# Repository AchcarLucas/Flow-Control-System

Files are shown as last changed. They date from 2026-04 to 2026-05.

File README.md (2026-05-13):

# 🚀 Monitor de Fluxo de Pessoas - Univesp - PI V




> [Sistema que verifica o fluxo de pessoas em um determinado local, registrando a entrada e a saída]

---

## 🔗 Integrantes do Grupo

| Nome Completo | NA |
| --- | --- |
| Livia Santos Paes | 2216192  |
| Lucas Campos Achcar | 23207401 |
| Luiz Fernando Sales Lemos | 2226810  |
| Maria Francisca Bezerra da Conceição | 2010316  |

---

## 📌 Sumário

* [Sobre o Projeto](#-sobre-o-projeto)
* [Tecnologias e Ferramentas](#-tecnologias-e-ferramentas)
* [Progresso do Desenvolvimento](#-progresso-do-desenvolvimento)
* [Estrutura do Projeto](#-estrutura-do-projeto)
* [Previa de Desenvolvimento](#-previa-de-desenvolvimento)

> 💡 **README Extra:**
> - [README Firmware](./Firmware/README.md)
> - [README Building Blocks](<./Building Blocks/README.md>)
> - [README Kicad Schematic](<./Kicad Schematic/README.md>)
> - [README Stripboard Schematic](<./Stripboard Schematic/README.md>)
---

## 🧩 Sobre o Projeto

O **Monitor de Fluxo de Pessoas** é uma solução de sistemas embarcados projetada para automatizar a contagem e o monitoramento de tráfego em ambientes fechados de forma autônoma e de baixo custo. O sistema utiliza um par de sensores ópticos infravermelhos para detectar não apenas a presença, mas a **direcionalidade do movimento**, permitindo distinguir com precisão entre entradas e saídas.

Diferente de soluções dependentes de nuvem, este projeto foca em **Edge Computing** (Processamento na Borda), onde a lógica de identificação de fluxo e o armazenamento dos registros ocorrem integralmente dentro do microcontrolador ESP32, garantindo privacidade e operabilidade mesmo sem conexão constante com a internet.

### 🧠 Diagrama de Blocos do Sistema

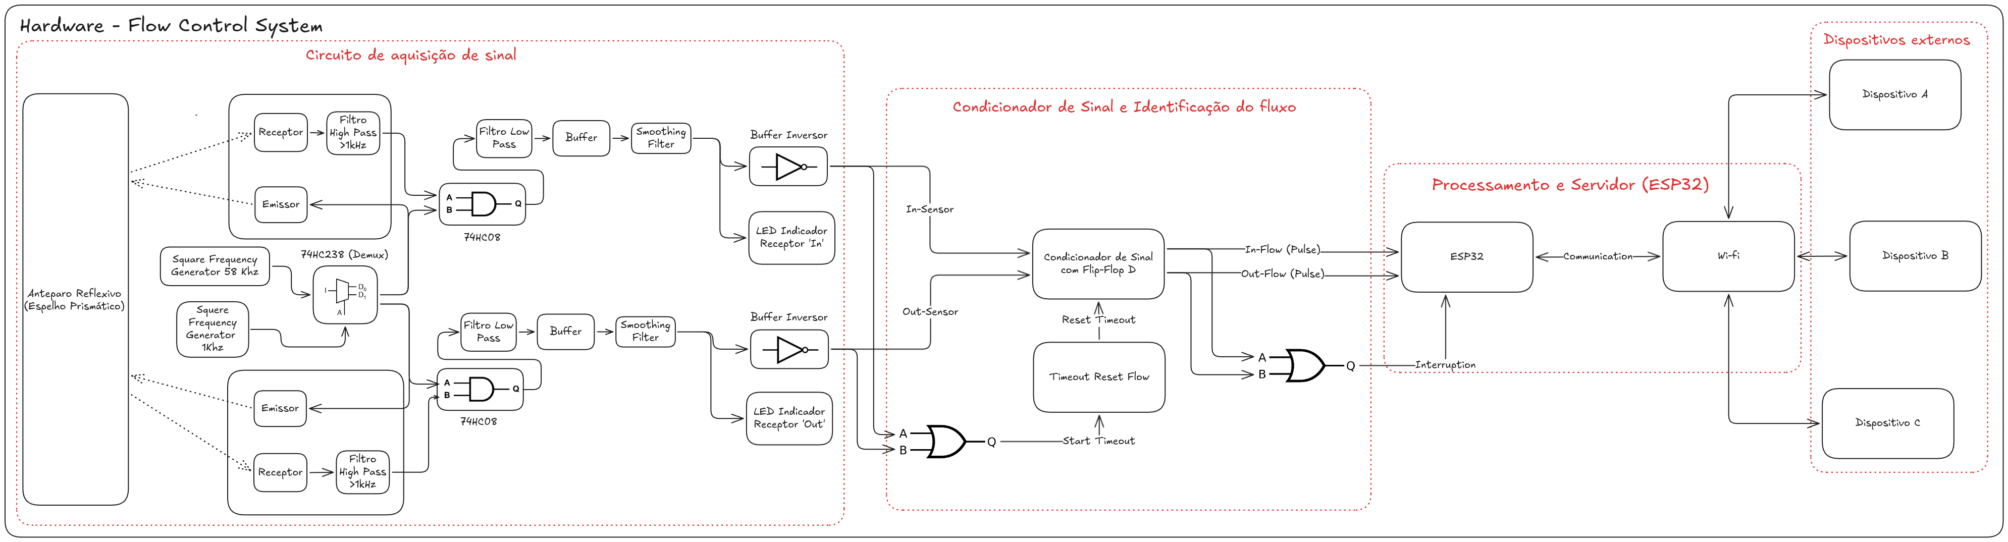
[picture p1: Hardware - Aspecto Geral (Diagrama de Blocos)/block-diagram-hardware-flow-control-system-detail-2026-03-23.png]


### ⚙️ Principais Funcionalidades

| Recurso | Descrição |
| :--- | :--- |
| **Detecção Direcional** | Circuito de tratamento de sinais que identifica o sentido do fluxo através do acionamento sequencial dos sensores. |
| **Condicionamento** | Circuito projetado para minimizar ruídos e falsos positivos, garantindo que a contagem reflita o fluxo real. |
| **Persistência Local** | Utilização da biblioteca **SQLite** para armazenamento robusto de logs no sistema de arquivos do ESP32, evitando perda de dados. |
| **Interface Web** | Servidor HTTP nativo que disponibiliza uma página para consulta em tempo real e visualização do histórico de acessos. |

---

## 🛠 Tecnologias e Ferramentas
* **Firmware:** [C++ | Arduino | PlatformIO]
* **Microcontrolador:** [ESP32 | ESP8266]
* **Linguagens:** [C++]
* **Banco de Dados:** [SQLite]
* **Simulações:** [SimulIDE]
* **CAD:** [Kicad e DIY Layout Creator]

## 🔧 Progresso do Desenvolvimento
|Status | Descrição |
| :--- | :--- |
| ✅ Concluído | Idealização do Projeto |
| ✅ Concluído | Prototipação do Enclosure do Fotosensor Utilizando CAD (Computer-Aided Design) |
| ✅ Concluído | Desenvolvimento do Firmware |
| ✅ Concluído | Alterações e Correções do Firmware |
| ✅ Concluído | Testes do Firmware para Identificação de Bugs e Leak de Memória |
| ✅ Concluído | Projeto e Prototipagem do Fotosensor |
| ✅ Concluído | Desenvolvimento da Enclusure para o Fotosensor |
| ✅ Concluído | Desenvolvimento do Schematic via Kicad |
| ✅ Concluído | Desenho dos Circuitos para Placa PadBoard usando a ferramenta DIY Layout Creator |
| ✅ Concluído | Teste do Circuito de Processamento na Protoboard|
| ✅ Concluído | Teste do Circuito de Aquisição de Sinal na Protoboard |
| ✅ Concluído | Teste do Circuito de Condicionamento, Identificação de Fluxo na Protoboard|
| ✅ Concluído | Desenvolvimento do Circuito de Fotosensor Placa PadBoard |
| ✅ Concluído | Desenvolvimento do Circuito de Aquisição de Sinal na Placa PadBoard |
| ✅ Concluído | Desenvolvimento do Circuito de Condicionamento, Identificação de Fluxo e Processamento na Placa PadBoard|
| ✅ Concluído | Prototipação do Enclosure da Mainboard Utilizando CAD |
| ✅ Concluído | Teste Final do Projeto na Todalidade |
| ✅ Concluído | Montagem Final do Projeto |

<!--
| ✅ Concluído | Text |
| 🟡 Desenvolvimento | Text |
| 🔴 Pendente | Text |
-->

## 📂 Estrutura do Projeto
Para facilitar a navegação, o projeto está dividido da seguinte forma:

```text
└── README.md                                           # [Detalhes do Projeto](./README.md)
├── Building Blocks/                                    # Prototipagem Geral do Sistema via CAD (SimulIDE)
    └── Processing e Server/                                    # Prototipação do ESP32 como WebServer e Processamento de Dados
    └── Emitter and Receiver                                    # Prototipação do Circuito do Fotosensor
    └── Signal Acquisition Circuit                              # Prototipação do Circuito de Aquisição de Sinais
    └── Signal Conditioning and Flow Identification Circuit     # Prototipação do Circuito de Condicionamento e Identificação de Fluxo
    └── README.md                                               # [Detalhes do Building Blocks](./Building Blocks/README.md)
├── Firmware/                                           # Código Fonte do Firmware do ESP32, Contém o WebServer e o Processamento de Sinais
    └── README.md                                               # [Detalhes do Firmware](./Firmware/README.md)
├── Hardware - Aspecto Geral (Diagrama de Blocos)/      # Idealização e Diagramação do Projeto Completo
├── Brainstorm/                                         # Brainstorm da Ideia Inicial
├── LTSpice/                                            # Simulações feitas via LTSpice para Auxilio do Desenvolvimento e Ajustes do Protótipo
├── Previa/                                             # Imagens e Animações de Previa do Projeto
├── Enclosure/                                          # Projeto das Cases Feito via FreeCAD
    └── FotosensorEnclosure                                     # Projeto da Case do Fotosensor feito em FreeCAD
    └── MainboardEnclosure                                      # Projeto da Case da Mainboard feito em FreeCAD
├── Kicad Schematic                                     # Schematic do Circuito Feito via Kicad
├── Stripboard Schematic/                               # Schematic do Circuito via DIY Layout Creator
```

## 🚀 Previa de Desenvolvimento

* ### Prototipo do Hardware para o Desenvolvimento do Firmware no ESP32

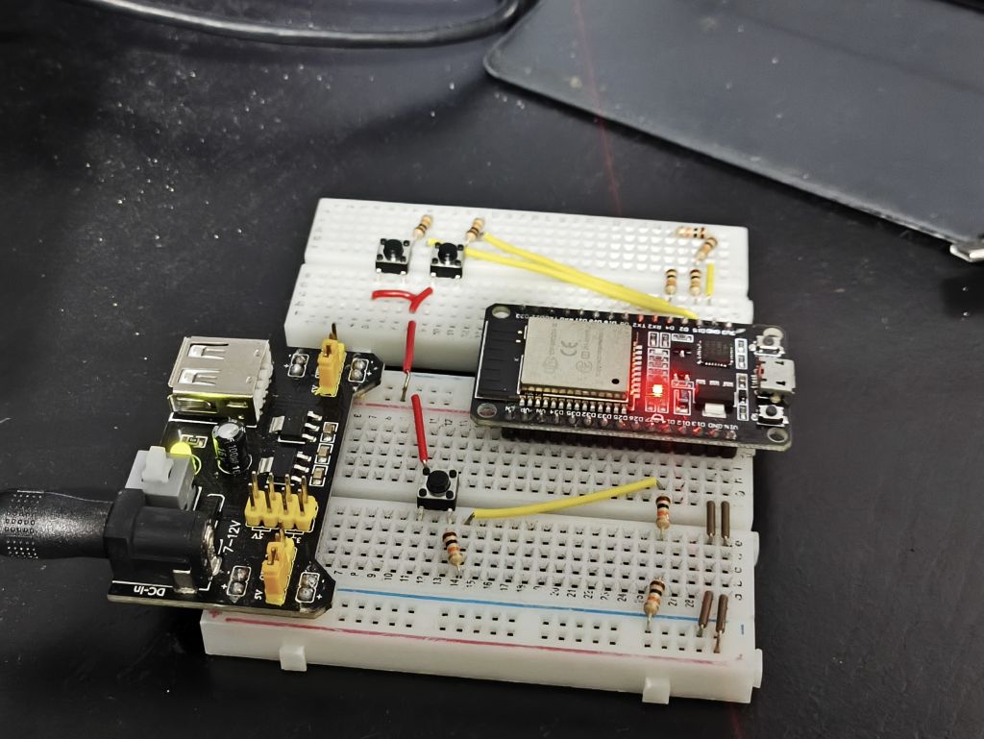
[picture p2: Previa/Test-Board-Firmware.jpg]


> 💡 **Detalhes da Placa de Teste:**
> - Os dois botões na parte de cima representam a entrada e a saída do fluxo.
> - O botão na parte de baixo representa a interrupção com detecção por borda de descida.

* ### Previa do 'Web Server' do Firmware

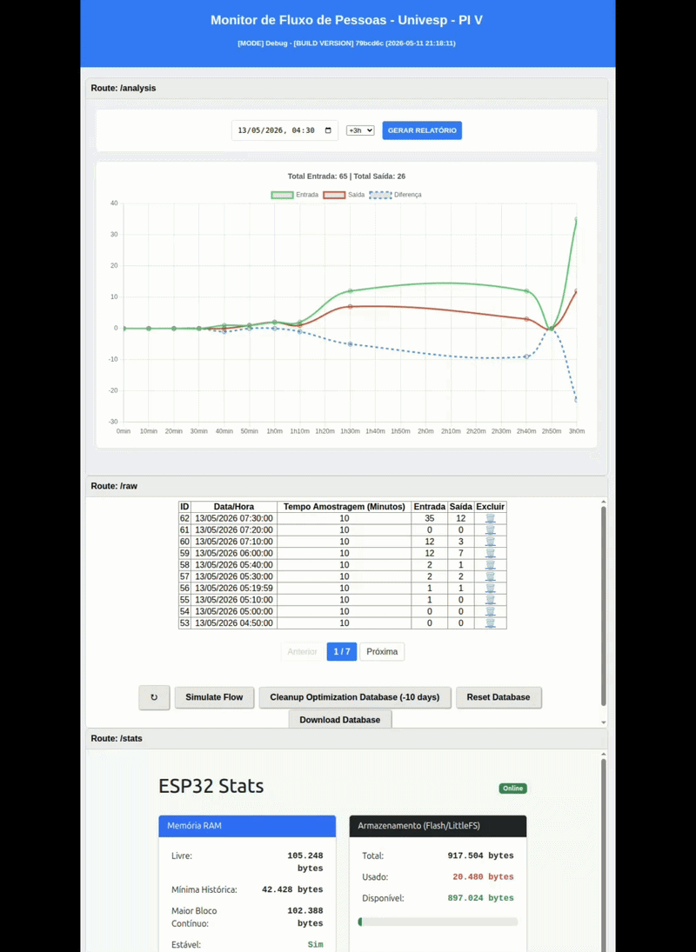
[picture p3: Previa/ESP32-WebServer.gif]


> 💡 **Detalhes do WebServer da Firmware:**
> - Servidor rodando diretamente no ESP32 - Edge Computing (Computador de Borda)
> - Gráfico para visualização dos dados em intervalos de horas
> - Planilha contendo os dados brutos (raw data)
> - Dashboard responsivo para celular e desktop.
> - Atualização em tempo real dos registros armazenados no SQLite.
> - Dashboard possui um sistema de stats para avaliação de desempenho do ESP32

* ### Protótipo do Circuito Completo em Protoboard

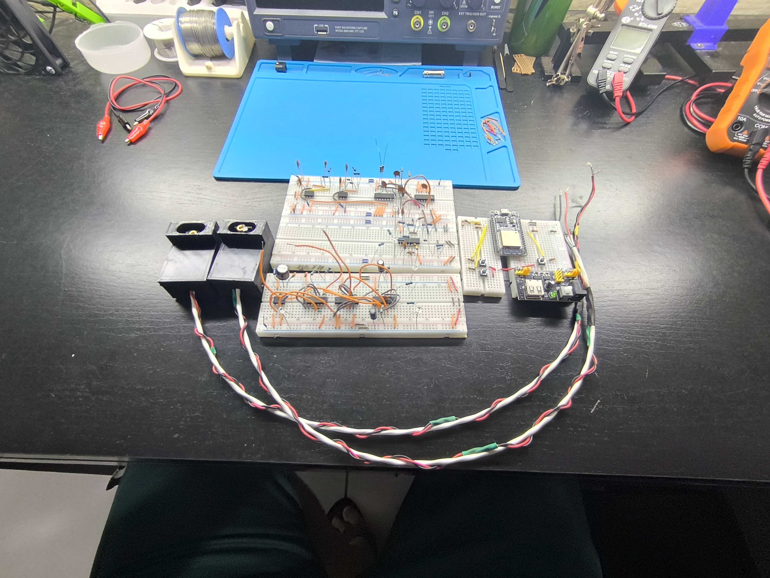
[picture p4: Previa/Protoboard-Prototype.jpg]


> 💡 **Detalhes do Protótipo:**
> - No canto esquerdo da imagem temos os dois fotosensores
> - No canto direito da imagem temos o prototipo do circuito de processamento
> - No centro superior da imagem temos o prototipo do circuito de condicionamento, identificação de fluxo 
> - No centro inferior da imagem temos o prototipo do circuito de aquisição de sinal

* ### Previa do Circuito Mainboard (Incompleto)

<div style="display: flex; gap: 10px;">
  
  
</div>

> 💡 **Detalhes do Circuito:**
> - Na esquerda, temos o circuito que faz a aquisição do sinal
> - Na direita, temos o circuito que faz o condicionamento e identificação do sentido além circuito de processamento (ESP32)
> - 📢 O circuito na direita ainda não esta completo

* ### Enclosure do Fotosensor

<div style="display: flex; gap: 10px;">
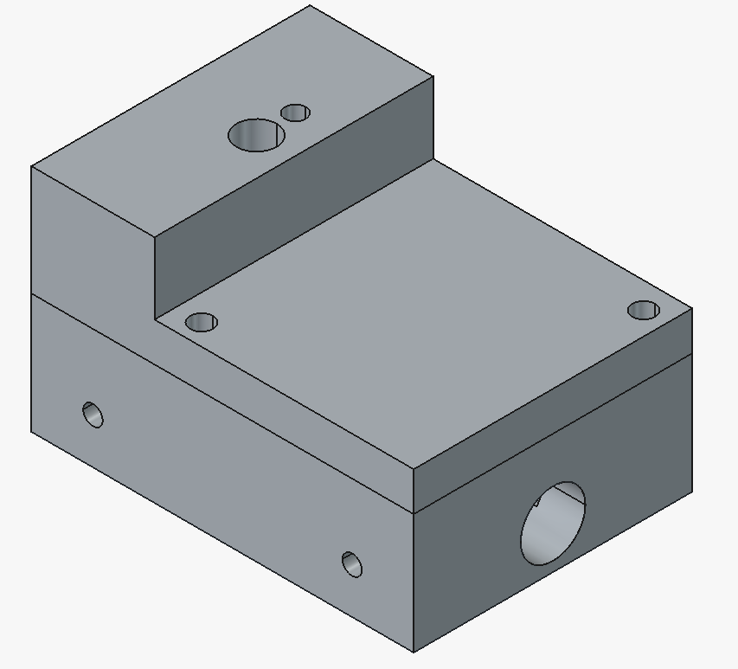
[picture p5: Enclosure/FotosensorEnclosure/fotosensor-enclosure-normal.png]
  
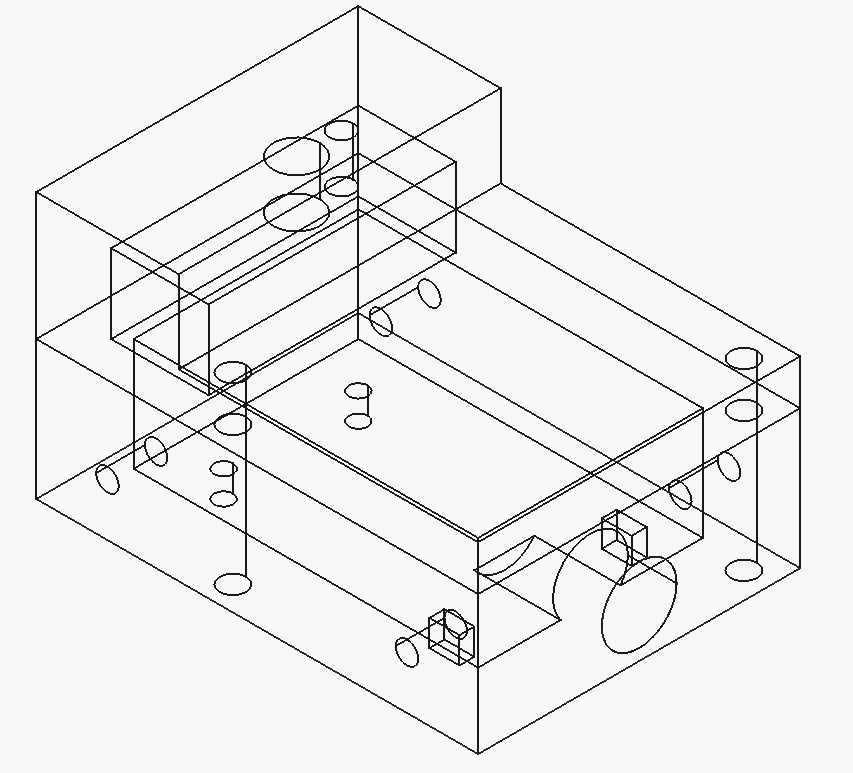
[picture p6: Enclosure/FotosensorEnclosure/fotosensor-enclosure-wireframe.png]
  
</div>

> 💡 **Detalhes do Enclosure do Fotosensor:**
> - [README FotosensorEnclosure](<./Enclosure/FotosensorEnclosure/README.md>)

* ### Enclosure da Mainboard

<div style="display: flex; gap: 10px;">
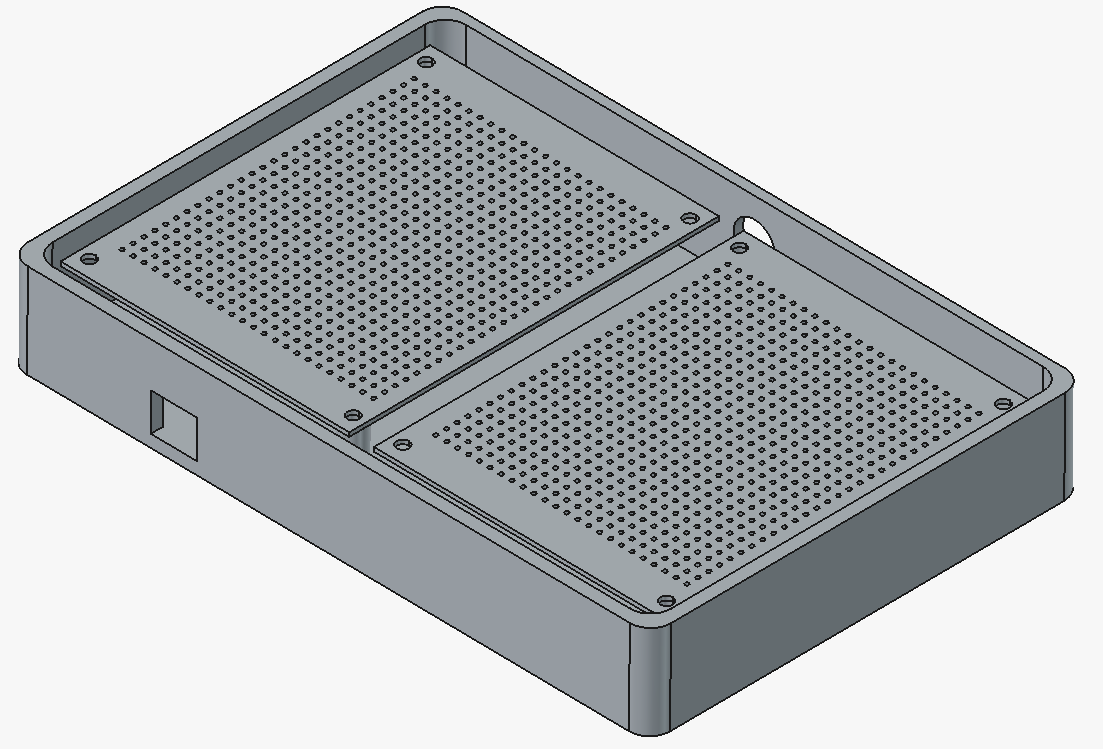
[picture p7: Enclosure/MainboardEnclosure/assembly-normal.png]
  
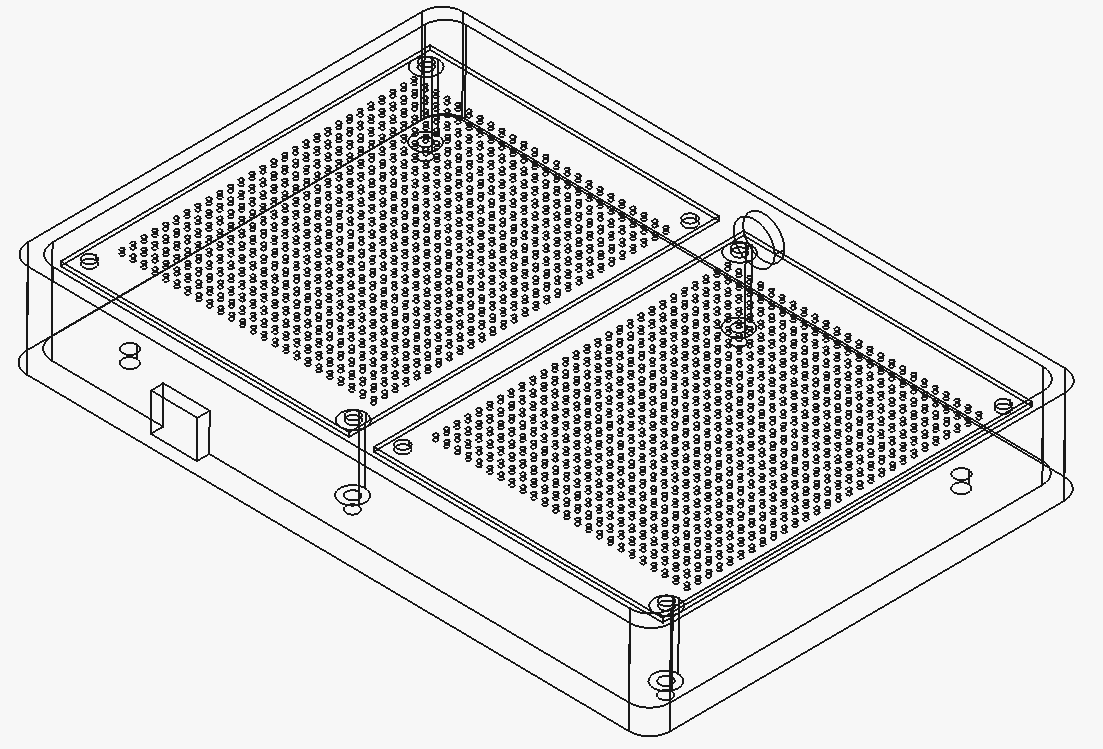
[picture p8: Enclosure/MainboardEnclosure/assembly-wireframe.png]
  
</div>

> 💡 **Detalhes do Enclosure da Mainboard:**
> - [README FotosensorEnclosure](<./Enclosure/MainboardEnclosure/README.md>)

## ✅ Projeto Concluído

<div style="display: flex; gap: 10px;">
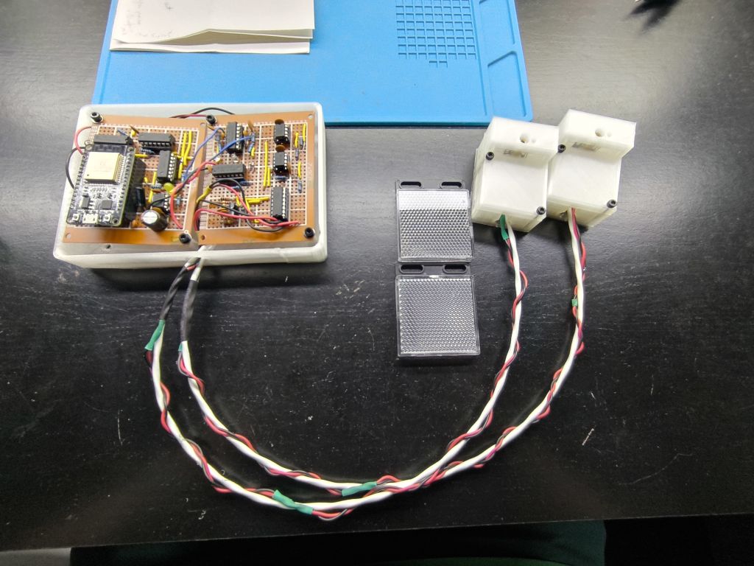
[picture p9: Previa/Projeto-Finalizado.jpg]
  
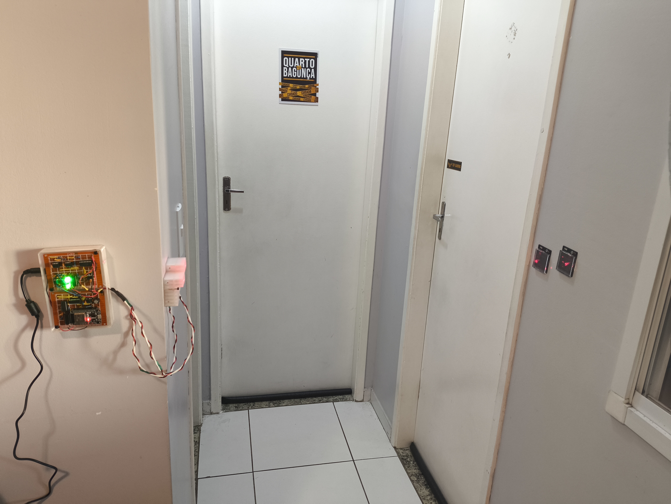
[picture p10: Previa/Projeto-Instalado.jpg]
  
</div>

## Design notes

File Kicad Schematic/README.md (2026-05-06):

# Projeto Integrador V - Monitor de Fluxo de Pessoas

Este diretório contém a documentação técnica, os esquemáticos eletrônicos e a lista de materiais (BOM) para o sistema de monitoramento de fluxo.

## 📂 Conteúdo do Diretório

O projeto é composto por três estágios principais, detalhados nos arquivos de imagem abaixo:

1.  **Emissor e Receptor (`emitter_and_receiver_schematic.png`)**:
    * Circuito de acionamento do diodo laser via transistor **BC547**.
    * Recepção de sinal via fototransistor **TIL78** com resistor de pull-up para gerar o sinal de saída.
2.  **Aquisição de Sinal (`signal_acquisition_schematic.png`)**:
    * Osciladores baseados no **NE555** para modulação em frequências distintas.
    * Filtragem ativa e demultiplexação utilizando portas **74LS08** e **74HC238** para garantir a imunidade a ruídos luminosos.
3.  **Condicionamento e Identificação de Fluxo (`signal_conditioning_and_flow_identification_schematic.png`)**:
    * Lógica de detecção de sentido (In/Out) utilizando Flip-Flops **74HC74**.
    * Tratamento de sinal com portas NAND Schmitt Trigger **4093** para debouncing e interface limpa com microcontroladores.
4.  **Processamento e Servidor (`processing-server-esp32-circuit.png`)**:
    * Receber o sinal de sentido (In-Flow/Out-Flow) nas portas do ESP32
    * Utilização de firmware para o sistema processamento e disponbilidade dos dados via web

<div style="display: flex; gap: 10px;">
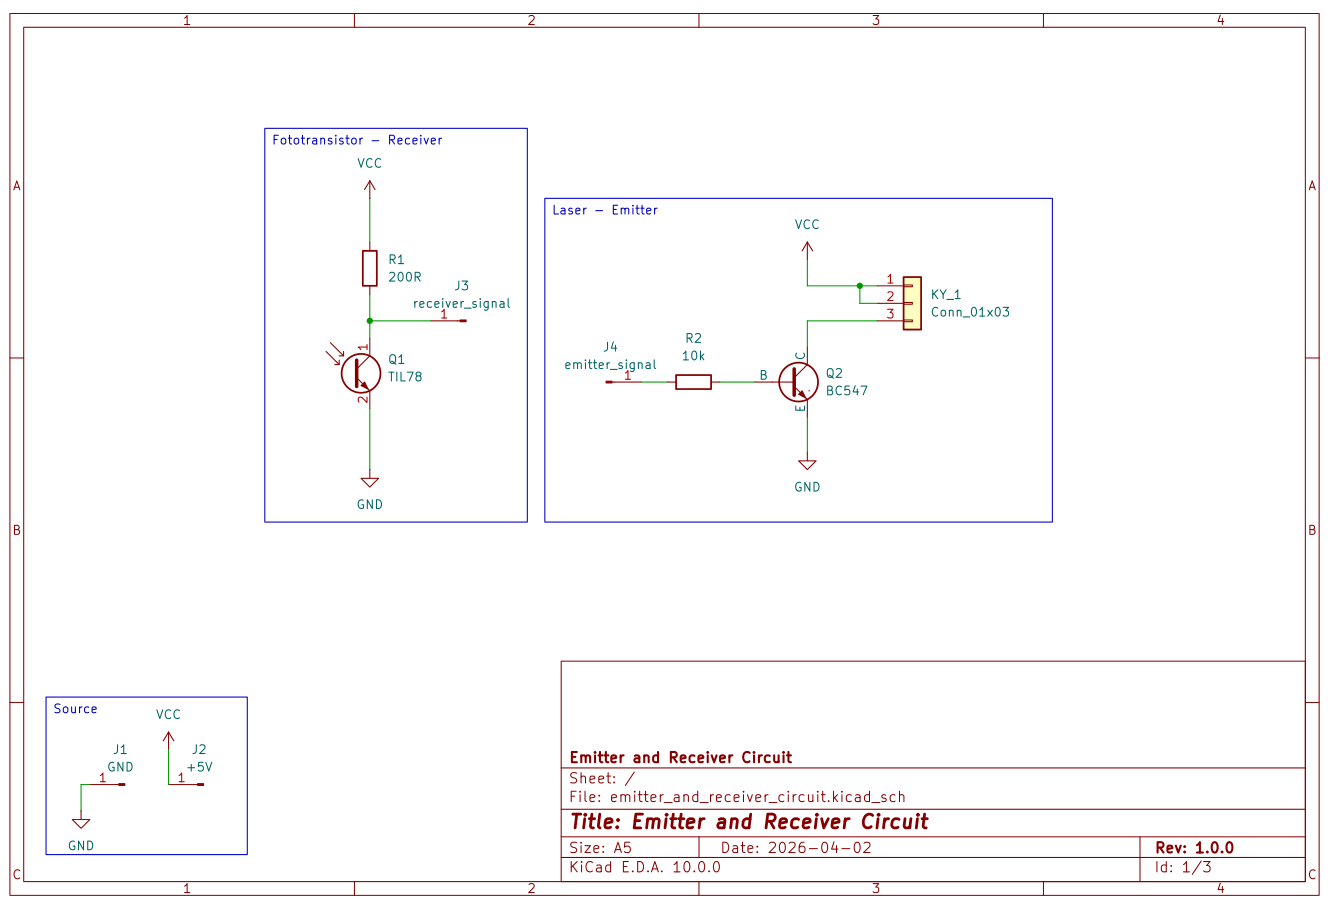
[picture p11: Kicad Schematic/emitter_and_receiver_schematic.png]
Emissor e Receptor
    
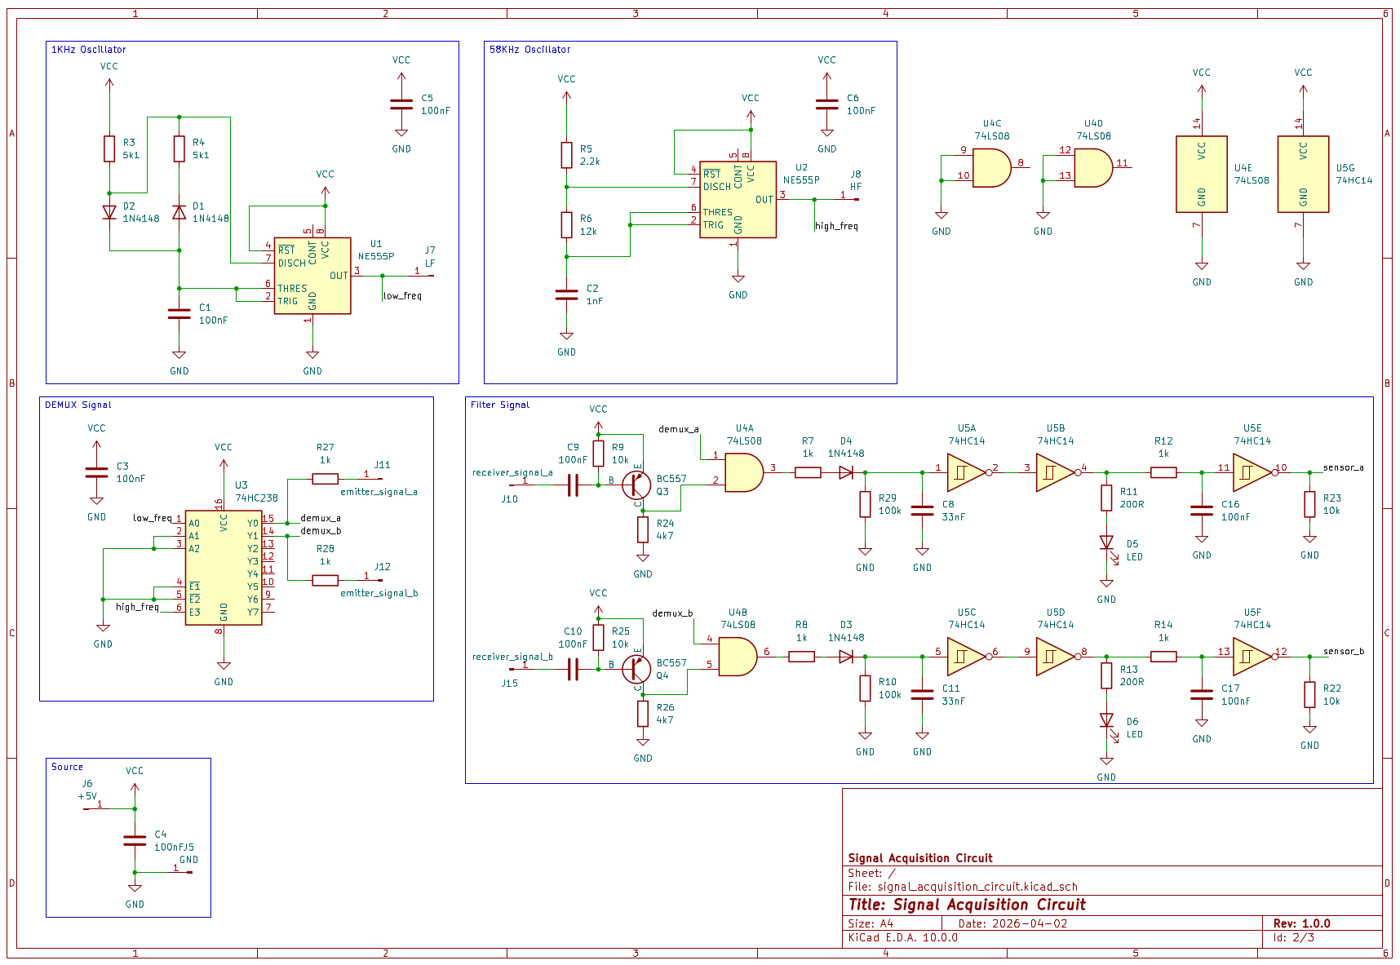
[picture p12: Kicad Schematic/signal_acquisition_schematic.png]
Aquisição de Sinal
    
    
</div>

<div style="display: flex; gap: 10px;">
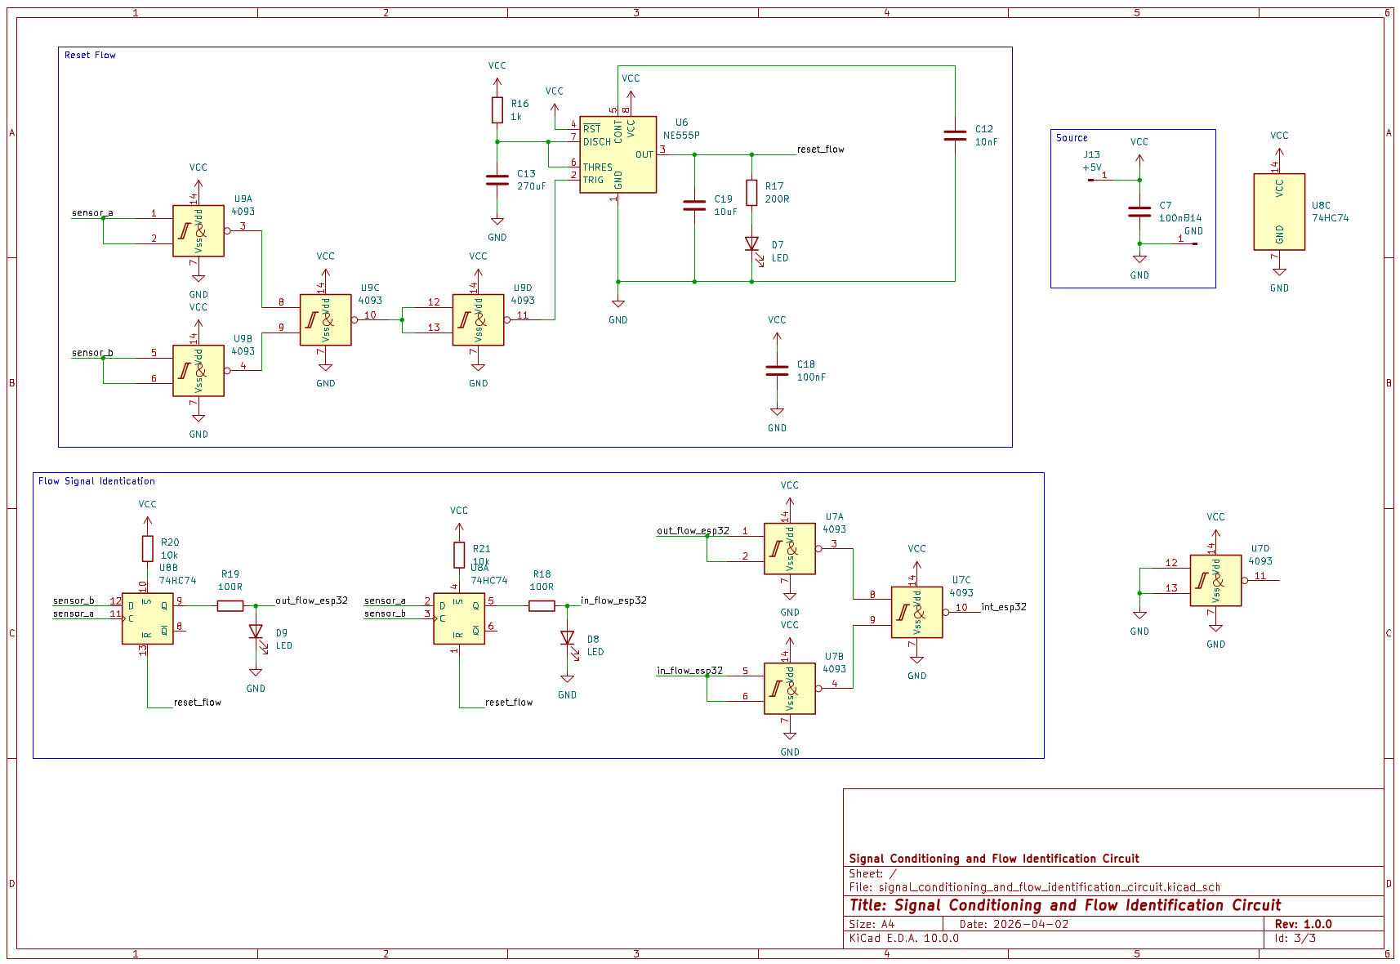
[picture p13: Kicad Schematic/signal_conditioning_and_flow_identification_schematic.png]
    
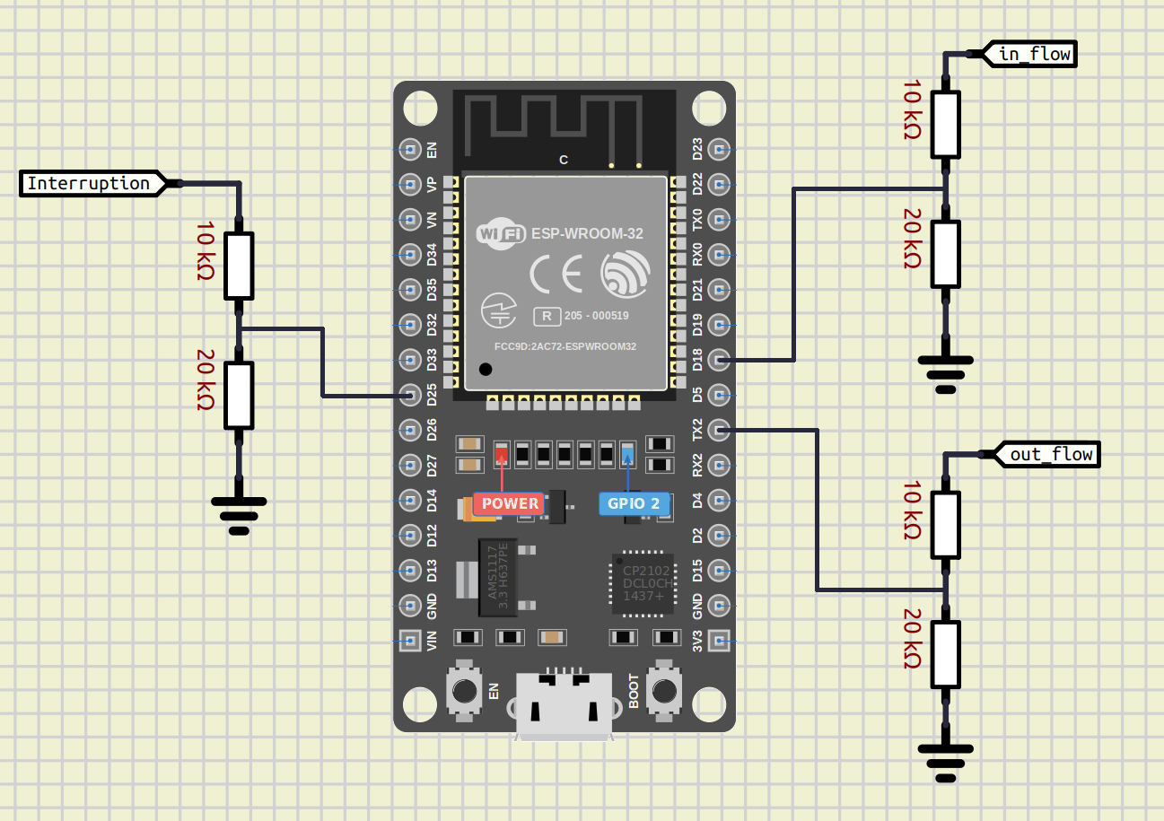
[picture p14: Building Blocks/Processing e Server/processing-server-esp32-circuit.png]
    
</div>

---

---

### 📑 Documentação em PDF

Para visualizar o projeto completo em alta resolução, acesse o link abaixo:
👉 **[Clique aqui para abrir o PDF do Esquemático](flow-control-system_schematic.pdf)**

---

## 📦 Lista de Componentes Detalhada (BOM)

Lista baseada no projeto de hardware, excluindo conectores de barra de pinos (Terminais JX).

### 1. Módulo Emitter e Receiver de Sinal (Duplicado)
| Categoria | Componente / Valor | Detalhes Técnicos | Referências | Qtd |
| :--- | :--- | :--- | :--- | :--- |
| **Sensores** | **TIL78** | Fototransistor NPN | Q1 | 02 |
| **Semicond.** | **BC547** | Transistor NPN | Q2 | 02 |
| **Resistor** | **200 $\Omega$** | Filme de Carbono | R1 | 02 |
| **Resistor** | **10k $\Omega$** | Filme de Carbono | R2 | 02 |
| **Conector** | **Conn_01x03** | Interface para Módulo Laser | KY_1 | 02 |

### 2. Módulo de Aquisição e Lógica de Sinal
| Categoria | Componente / Valor | Detalhes Técnicos | Referências | Qtd |
| :--- | :--- | :--- | :--- | :--- |
| **CIs** | **NE555P** | Temporizador / Oscilador | U1, U2 | 02 |
| **CIs** | **74HC238** | Demultiplexador 3-para-8 | U3 | 01 |
| **CIs** | **74LS08** | Quad 2-Input AND Gate | U4 | 01 |
| **CIs** | **74HC14** | Hex Inverting Schmitt Trigger | U5 | 01 |
| **Semicond.** | **BC557** | Transistor PNP | Q3, Q4 | 02 |
| **Semicond.** | **1N4148** | Diodo de sinal rápido | D1, D2, D3, D4 | 04 |
| **Indicador** | **LED** | Sinalização de Feixe/Status | D5, D6 | 02 |
| **Capacitor** | **100nF** | Cerâmico (Desacoplamento) | C1, C3-C6, C9, C10, C16, C17 | 09 |
| **Capacitor** | **33nF** | Cerâmico / Poliéster | C8, C11 | 02 |
| **Capacitor** | **1nF** | Cerâmico | C2 | 01 |
| **Resistor** | **100k $\Omega$** | Filme de Carbono | R10, R29 | 02 |
| **Resistor** | **12k $\Omega$** | Filme de Carbono | R6 | 01 |
| **Resistor** | **10k $\Omega$** | Filme de Carbono | R9, R25, R22, R23 | 04 |
| **Resistor** | **5k1 $\Omega$** | Filme de Carbono | R3, R4 | 02 |
| **Resistor** | **4k7 $\Omega$** | Filme de Carbono | R24, R25 | 02 |
| **Resistor** | **2k2 $\Omega$** | Filme de Carbono | R5 | 01 |
| **Resistor** | **1k $\Omega$** | Filme de Carbono | R7, R8, R12, R14, R27, R28 | 06 |
| **Resistor** | **200 $\Omega$** | Filme de Carbono | R11, R13 | 02 |

### 3. Condicionamento e Identificação de Fluxo
| Categoria | Componente / Valor | Detalhes Técnicos | Referências | Qtd |
| :--- | :--- | :--- | :--- | :--- |
| **CIs** | **NE555P** | Temporizador / Oscilador | U6 | 01 |
| **CIs** | **CD4093** | Quad 2-Input NAND Schmitt Trigger | U7, U9 | 02 |
| **CIs** | **74HC74** | Dual D-Type Flip-Flop | U8 | 01 |
| **Indicador** | **LED** | Sinalização de Feixe/Status | D7, D8, D9 | 03 |
| **Resistor** | **10k $\Omega$** | Filme de Carbono | R20, R21 | 02 |
| **Resistor** | **1k $\Omega$** | Limitação de corrente LED | R16 | 01 |
| **Resistor** | **200 $\Omega$** | Filme de Carbono | R17 | 01 |
| **Resistor** | **100 $\Omega$** | Limitação de corrente LED | R18, R19 | 02 |
| **Capacitor** | **270uF** | Eletrolítico (Filtro/Reset) | C13 | 01 |
| **Capacitor** | **10uF** | Eletrolítico (Estabilização) | C19 | 01 |
| **Capacitor** | **100nF** | Cerâmico (Desacoplamento) | C7, C18 | 02 |
| **Capacitor** | **10nF** | Cerâmico (Desacoplamento) | C12 | 01 |

### 4. Processamento e Servidor (IoT)
Módulo responsável pela leitura dos pulsos lógicos, processamento dos dados de contagem e transmissão via rede.

| Categoria | Componente / Valor | Detalhes Técnicos | Qtd |
| :--- | :--- | :--- | :--- |
| **MCU** | **ESP32** | Microcontrolador com Wi-Fi/Bluetooth | 01 |
| **Resistor** | **20k $\Omega$** | Divisor de tensão / Condicionamento | 03 |
| **Resistor** | **10k $\Omega$** | Pull-up / Pull-down de interface | 03 |
| **Capacitor** | **100nF** | Cerâmico (Desacoplamento ESP32) | 01 |

---
*Nota: Os esquemáticos foram desenvolvidos em KiCad. Terminais de alimentação e pontos de teste (J1-J14) estão presentes nos desenhos técnicos, mas foram omitidos desta lista de componentes para simplificação da compra de materiais.*

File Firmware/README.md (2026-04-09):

# 🚀 Monitor de Fluxo de Pessoas - ESP32 & SQLite3

Sistema de monitoramento de fluxo de pessoas desenvolvido para o **Projeto Integrador Univesp**. O projeto utiliza um ESP32 para contagem via sensores ópticos, com persistência de dados em banco de dados relacional **SQLite3** e interface de gerenciamento via Web.

## 📋 Funcionalidades
* **Contagem em Tempo Real:** Detecção de passagem via interrupções de hardware.
* **Banco de Dados Local:** Armazenamento robusto com SQLite3 sobre a partição LittleFS.
* **Interface Web Assíncrona:** Visualização de dados e comandos via navegador sem travar o processador.
* **Sincronização NTP:** Registro automático de data/hora real (Fuso Brasília UTC-3).
* **Auto-Limpeza:** Rotina automática que remove registros com mais de X meses para otimização de espaço.
* **Exportação de Dados:** Rota direta para download do arquivo `.db` para análise no PC.

## 📚 Bibliotecas Necessárias (Dependencies)

Independente da IDE utilizada (PlatformIO ou Arduino IDE), as seguintes bibliotecas são obrigatórias:

1.  **Sqlite3Esp32** (por Siara-cc): Motor do banco de dados.
2.  **ESPAsyncWebServer** (por me-no-dev): Servidor Web de alta performance.
3.  **AsyncTCP** (por me-no-dev): Base para o servidor assíncrono.
4.  **LittleFS** (Nativa do Core ESP32): Gerenciamento da memória Flash.
5.  **Time** (Nativa do C): Sincronização e manipulação de data/hora.

## 🛠️ Estrutura de Partições (partitions.csv)
O projeto requer uma partição customizada para acomodar o banco de dados. Recomendado:
* **App (Firmware):** 3MB
* **SPIFFS/LittleFS (Data):** ~944KB

## 🌐 Endpoints Page Local
| Rota | Descrição |
| :--- | :--- |
| `GET /` | Página principal do sistema. |
| `GET /analysis` | Filtro e gráfico de análise dos dados do sistema. |
| `GET /raw` | Tabulação com os dados brutos do sistema. |
| `GET /stats` | Exibição do estado (saúde) do sistema. |
## 🌐 Endpoints Request Local
| Rota | Descrição |
| :--- | :--- |
| `GET /simulate` | Simulação de incremento de fluxo (Inserção SQL). |
| `GET /cleanup` | Limpeza os dados antigos para otimização do banco de dados. |
| `GET /reset` | Limpeza total dos dados do banco de dados |
| `GET /download` | Download do arquivo database `.db` do sistema. |
## 🌐 Endpoints da API Local
| Rota | Descrição |
| :--- | :--- |
| `GET /sample_api` | Obtém os dados das amostras em relação a uma data inicial e final |
| `GET /stats_api` | Obtém os dados de memória e armazenamento do ESP32 |

## 🔧 Configurações

A rede `WIFI_SSID` e `WIFI_PASSWORD` devem ser configurado no `env/.env`, faça uma copia do `env/.env-example` com o nome `env/.env` e adicione sua rede wifi

Outras configurações podem ser feitas via ```platformio.ini```

O sistema está configurado para o horário de **São Paulo/SP (UTC-3)**:

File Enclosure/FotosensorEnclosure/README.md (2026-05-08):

# FotosensorEnclosure

Esta pasta contém o design da carcaça (enclosure) para o fotosensor do Sistema de Controle de Fluxo.

## Arquivos

- `FotosensorEnclosure.FCStd`: Arquivo de projeto do FreeCAD contendo o design 3D da carcaça.
- `fotosensor-enclosure-normal.png`: Imagem de referência do design da carcaça.
- `fotosensor-enclosure-wireframe.png`: Imagem de referência do design da carcaça em wireframe.
- `FotosensorEnclosure-Body-Bottom.obj`: Modelo 3D da parte inferior da carcaça (formato OBJ).
- `FotosensorEnclosure-Body-Top.obj`: Modelo 3D da parte superior da carcaça (formato OBJ).

## Imagem de Referência

Fotosensor Enclosure Normal
Fotosensor Enclosure Wireframe

## Descrição

A carcaça do fotosensor é projetada para proteger o sensor óptico utilizado na detecção de fluxo no sistema de controle. O design inclui partes superior e inferior para facilitar a montagem e manutenção.

## Montagem

Para montar a carcaça, utilize 2 parafusos M3x10 ou de comprimento superior, junto com as respectivas porcas de fusão térmica (insertos térmicos).

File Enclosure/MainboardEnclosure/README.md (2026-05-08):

# MainboardEnclosure

Esta pasta contém o design da carcaça (enclosure) para a placa principal (mainboard) do Sistema de Controle de Fluxo.

## Arquivos

- `MainboardEnclosure.FCStd`: Arquivo de projeto do FreeCAD contendo o design 3D da carcaça.
- `MainboardEnclosure.obj`: Modelo 3D da carcaça (formato OBJ).
- `Spacer.obj`: Modelo 3D do espaçador (spacer) (formato OBJ).
- `assembly-normal.png`: Imagem da montagem em vista normal.
- `assembly-wireframe.png`: Imagem da montagem em vista wireframe.
- `mainboard-enclosure-normal.png`: Imagem da carcaça em vista normal.
- `mainboard-enclosure-wireframe.png`: Imagem da carcaça em vista wireframe.
- `spacer.png`: Imagem do espaçador.

## Imagens de Referência

### Carcaça da Placa Principal
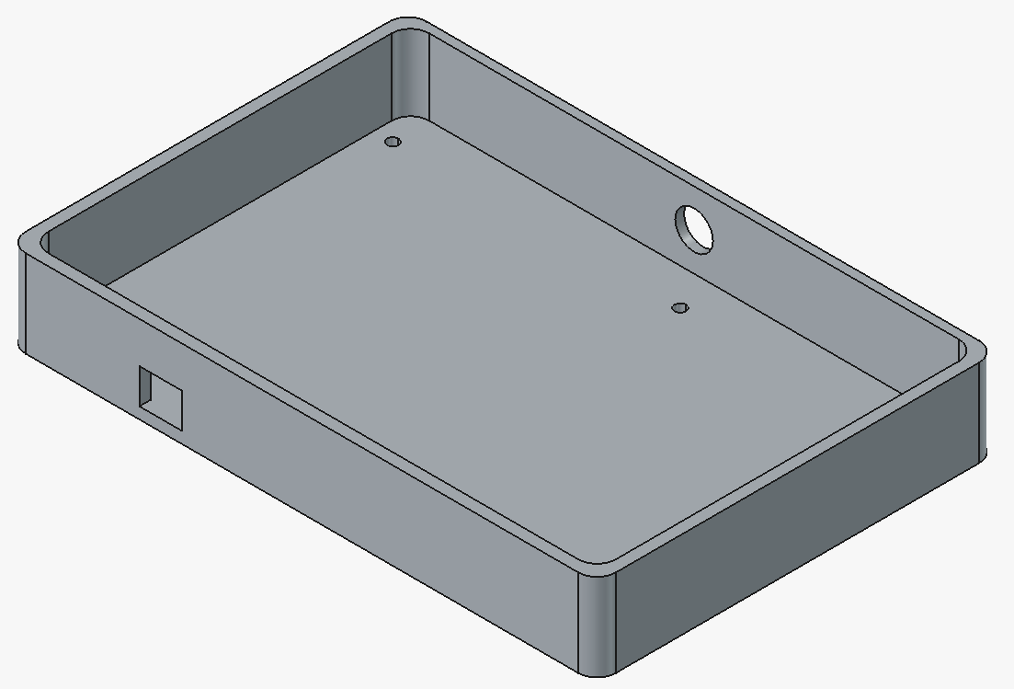
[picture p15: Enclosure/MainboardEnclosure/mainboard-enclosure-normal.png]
Mainboard Enclosure Normal

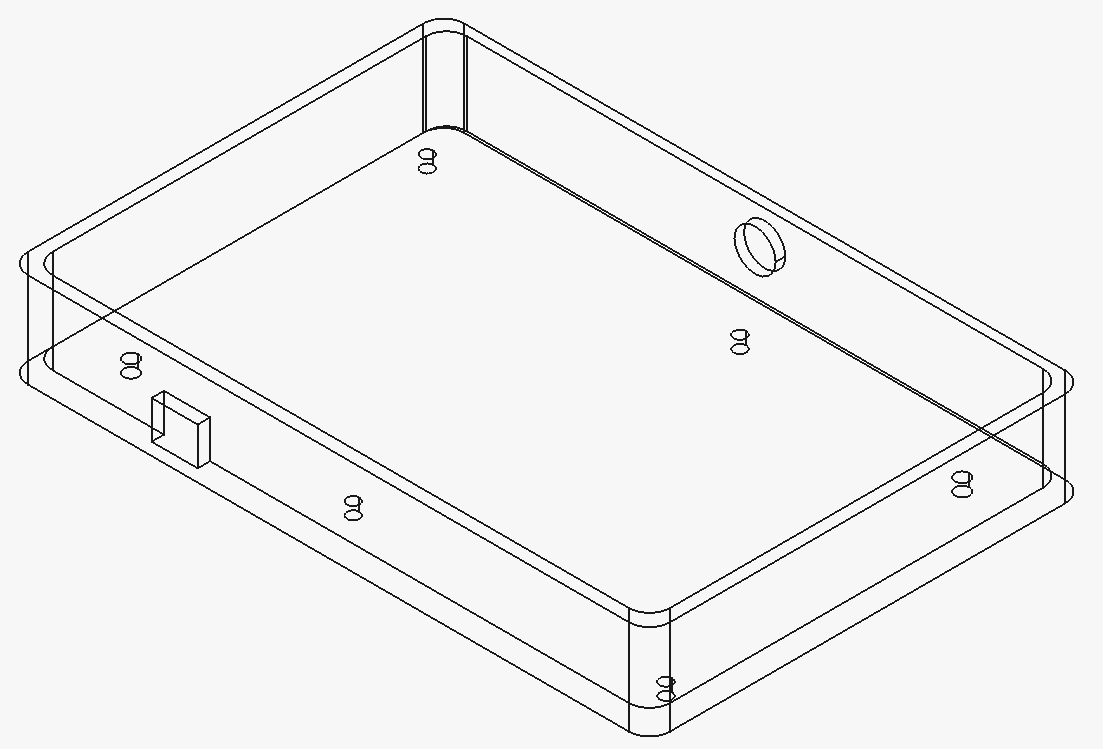
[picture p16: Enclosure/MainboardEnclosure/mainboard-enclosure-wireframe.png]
Mainboard Enclosure Wireframe


### Montagem
Assembly Normal
Assembly Wireframe

### Espaçador
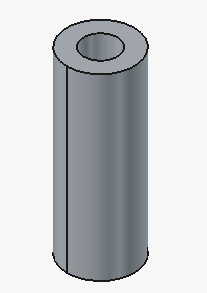
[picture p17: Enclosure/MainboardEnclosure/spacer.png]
Spacer


## Descrição

A carcaça da placa principal é projetada para proteger e fixar a placa de circuito principal do sistema de controle de fluxo. Inclui um espaçador para isolamento e montagem adequada.

## Montagem

Para montar a carcaça, utilize 4 parafusos M3x20 ou M3.5x20 (Recomendado). Os parafusos criam rosca diretamente no plástico, não sendo necessários insertos ou porcas adicionais.

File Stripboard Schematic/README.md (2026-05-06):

## 🔗 Stripboard Schematic do Projeto

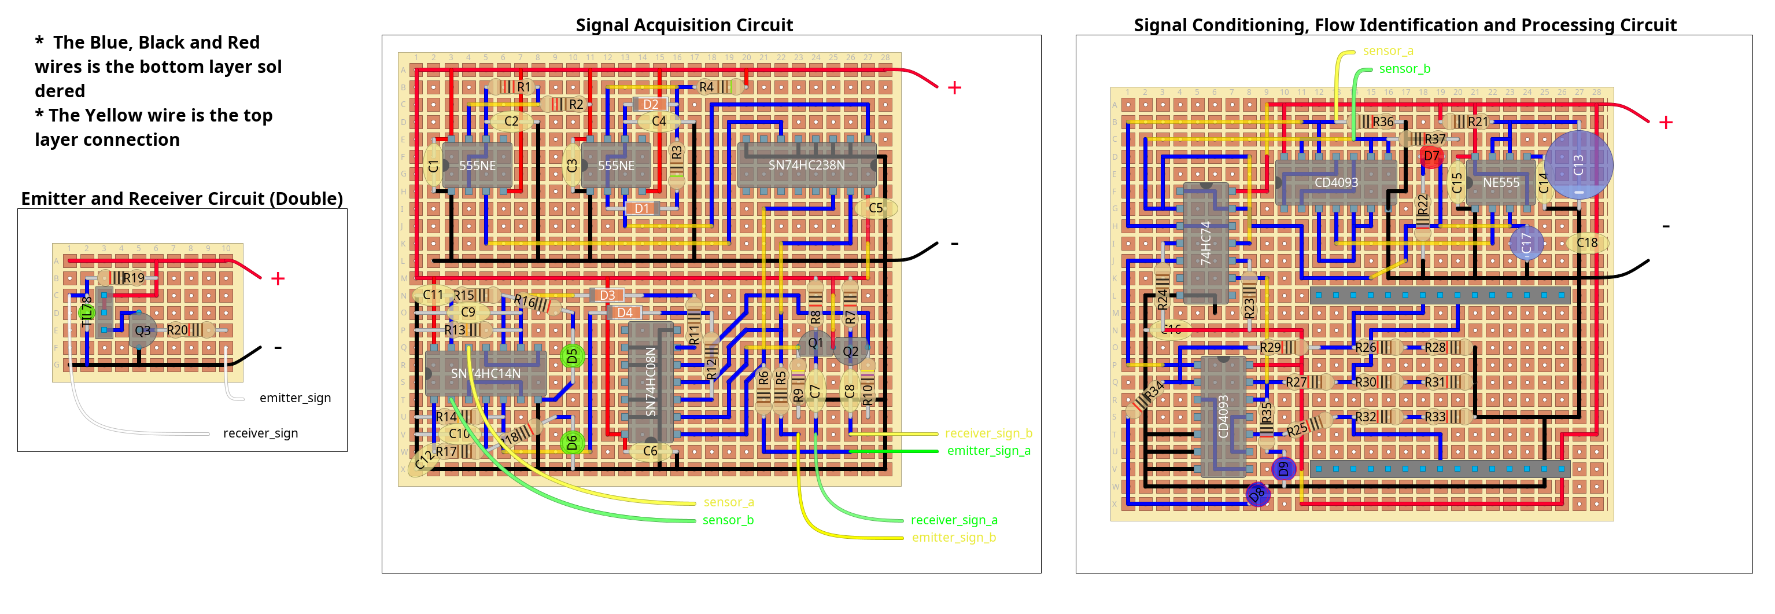
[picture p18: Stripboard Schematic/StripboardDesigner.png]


> 💡 **Detalhes:**
> - Para a criação do esquemático stripboard foi utilizado o software 'DIY Layout Creator'
> - Para mais detalhes, acesse https://diy-fever.com/software/diylc/

### 📑 Documentação em PDF

Para visualizar o projeto completo em alta resolução, acesse o link abaixo:
👉 **[Clique aqui para abrir o PDF do Stripboard](StripboardDesigner.pdf)**

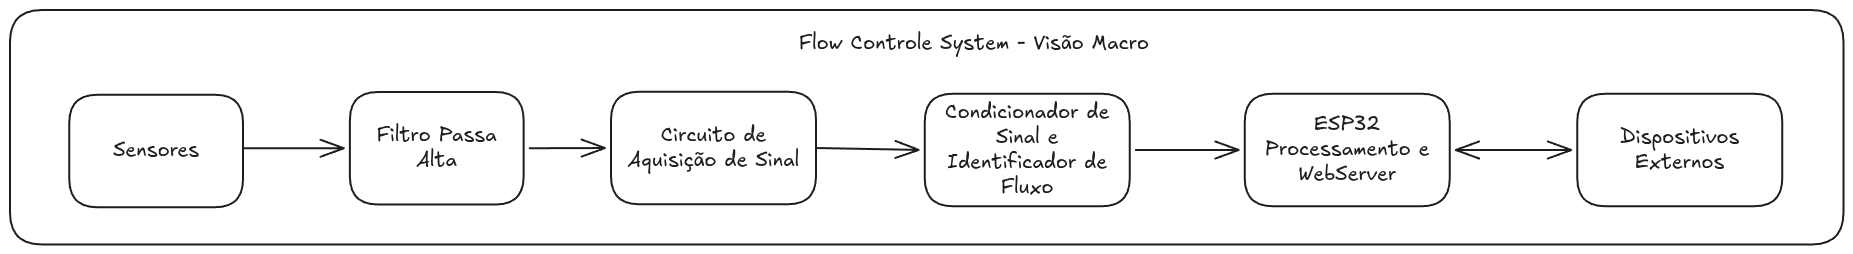
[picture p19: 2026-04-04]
Hardware - Aspecto Geral (Diagrama de Blocos)/flow-control-system-macro.png

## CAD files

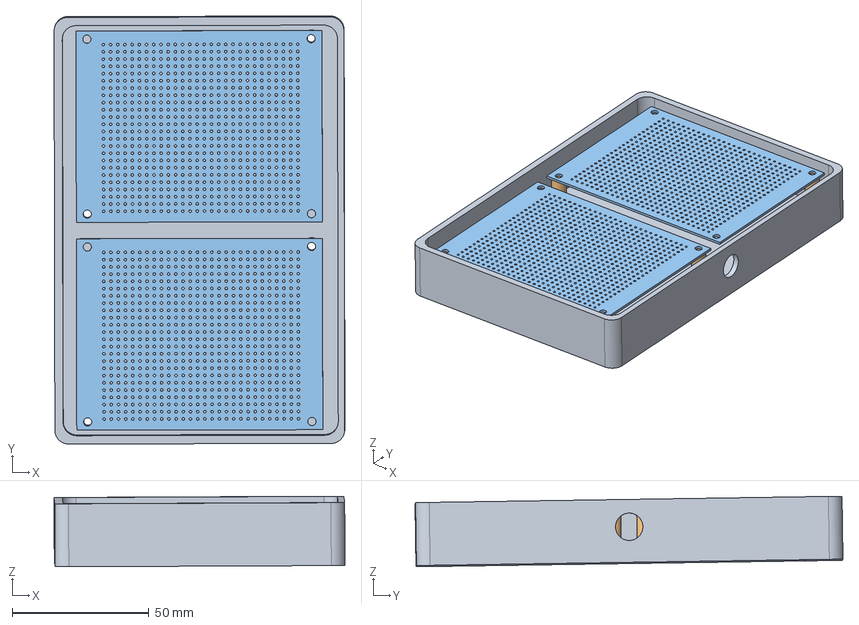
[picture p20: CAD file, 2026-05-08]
Enclosure/MainboardEnclosure/MainboardEnclosure.FCStd
106.4 x 156.5 x 25.8 mm
MainboardEnclosure
Spacer x 4
Stripboard x 2

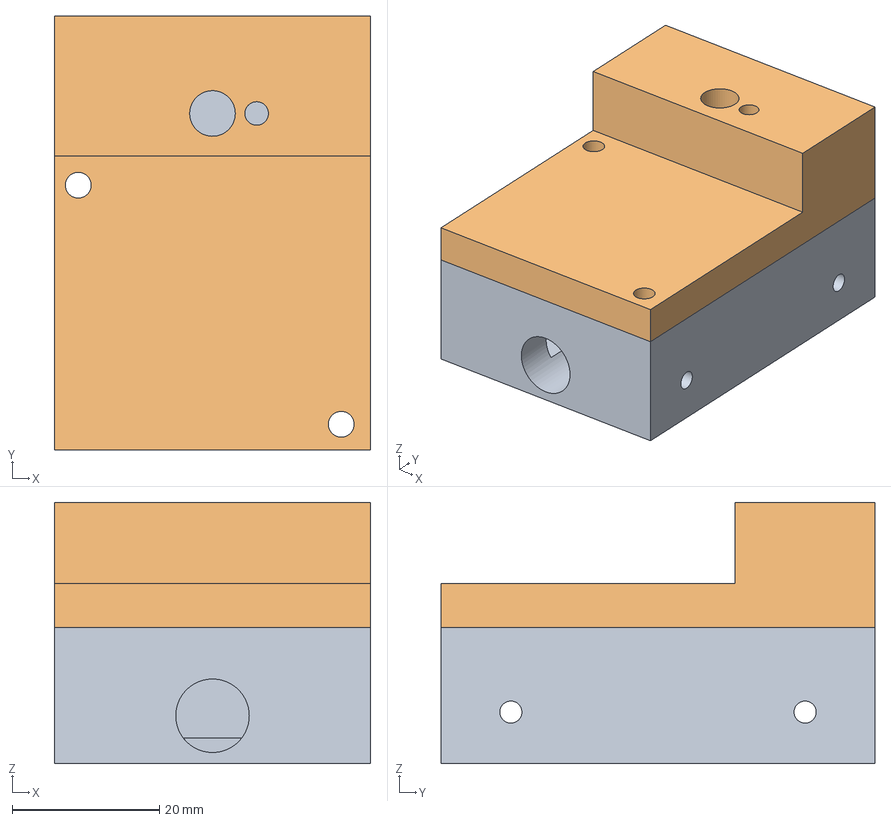
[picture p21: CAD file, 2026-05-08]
Enclosure/FotosensorEnclosure/FotosensorEnclosure.FCStd
43.0 x 59.0 x 35.5 mm
Body-Bottom
Body-Top

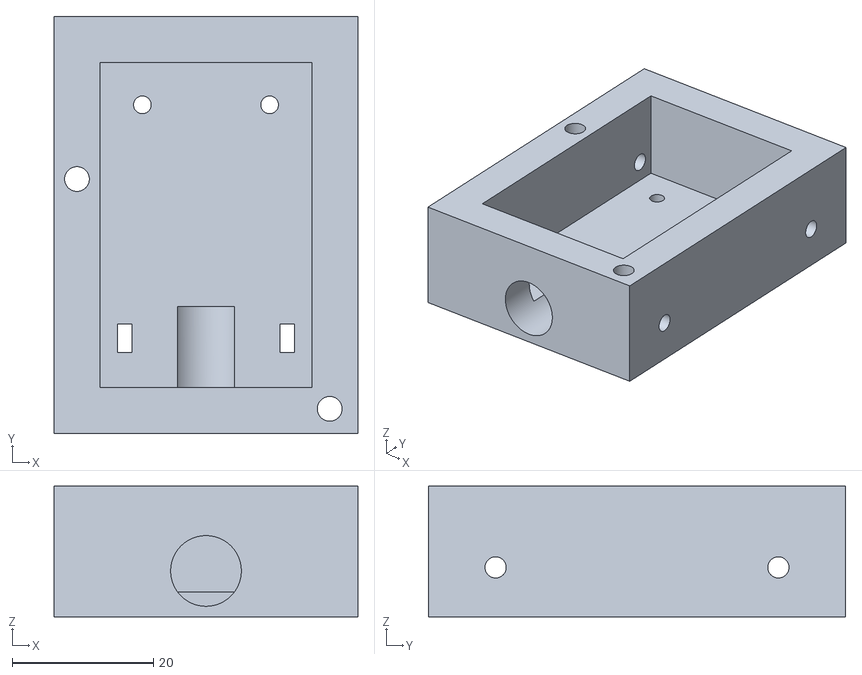
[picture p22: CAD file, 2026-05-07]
Enclosure/FotosensorEnclosure/FotosensorEnclosure-Body-Bottom.obj
43.0 x 59.0 x 18.5

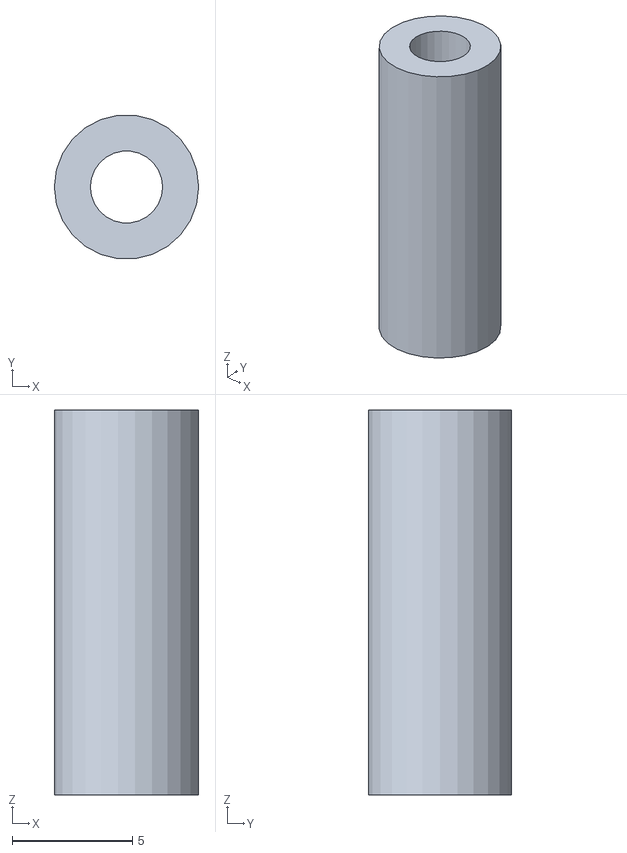
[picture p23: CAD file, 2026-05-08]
Enclosure/MainboardEnclosure/Spacer.obj
6.00 x 5.96 x 16.0

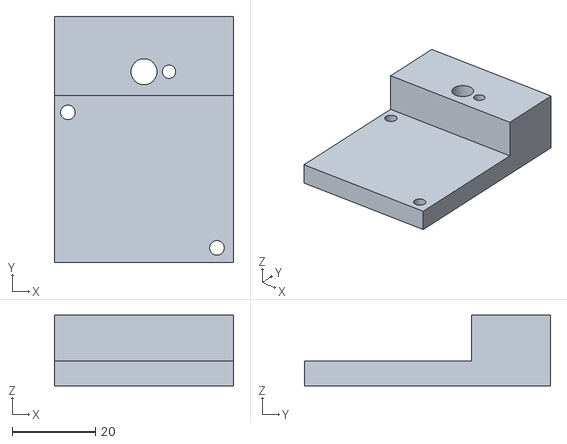
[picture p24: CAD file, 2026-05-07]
Enclosure/FotosensorEnclosure/FotosensorEnclosure-Body-Top.obj
43.0 x 59.0 x 17.0

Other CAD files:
Enclosure/MainboardEnclosure/MainboardEnclosure.obj

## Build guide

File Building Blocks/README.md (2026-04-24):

# Sistema de Monitoramento de Fluxo de Pessoas (Projeto Integrador V)

Este projeto consiste em um sistema de monitoramento de fluxo capaz de identificar a direção do movimento (entrada e saída) através de sensores ópticos e lógica digital, integrando os dados a um servidor web hospedado em um **ESP32**.

---

## 🛠️ Ferramentas e Tecnologias

### Software
* **[SimulIDE 1.0.0](https://simulide.com/p/)**: Software para a simulação dos circuitos.
* **[Visual Studio Code](https://code.visualstudio.com/)**: IDE para Programação do Firmware.
* **[PlatformIO](https://platformio.org/)**: Embedded Software Development para ESP32.
* **[ESP-IDF / Arduino](https://www.arduino.cc/en/software/)**: Ambiente de compilação do Firmware ESP32.

### Hardware
* **Microcontrolador**: ESP32 (Servidor e Processamento).
* **Arquitetura**: Circuitos integrados CMOS/TTL para processamento de sinal em tempo real.

## 📑 Documentação Técnica

### 1. Módulo de Aquisição de Sinal

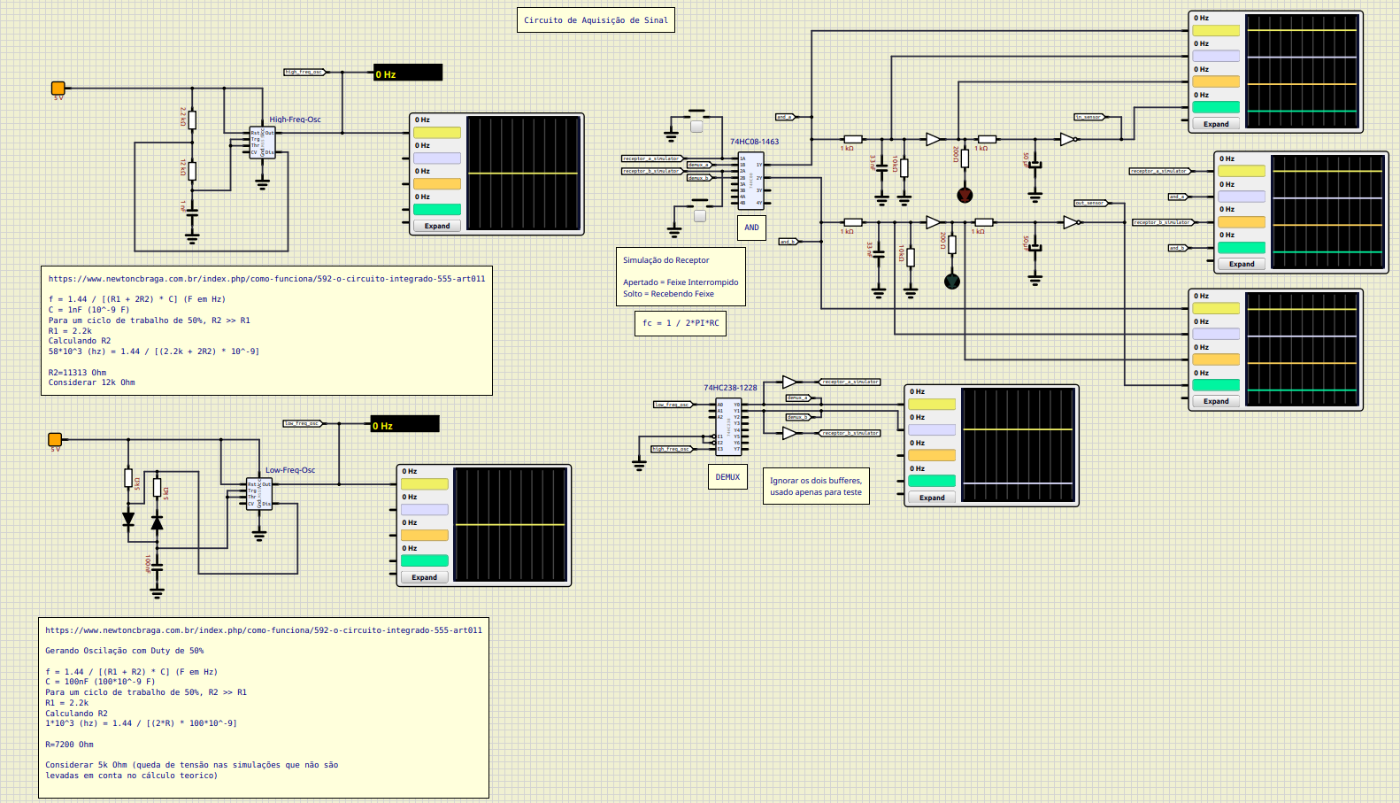
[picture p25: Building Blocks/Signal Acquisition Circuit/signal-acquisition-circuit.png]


O objetivo deste estágio é converter a interrupção física de um feixe óptico em um sinal digital limpo, imune a interferências externas.

#### 1.1. Modulação e Portadora (Osciladores 555)

<div style="display: flex; gap: 10px;">
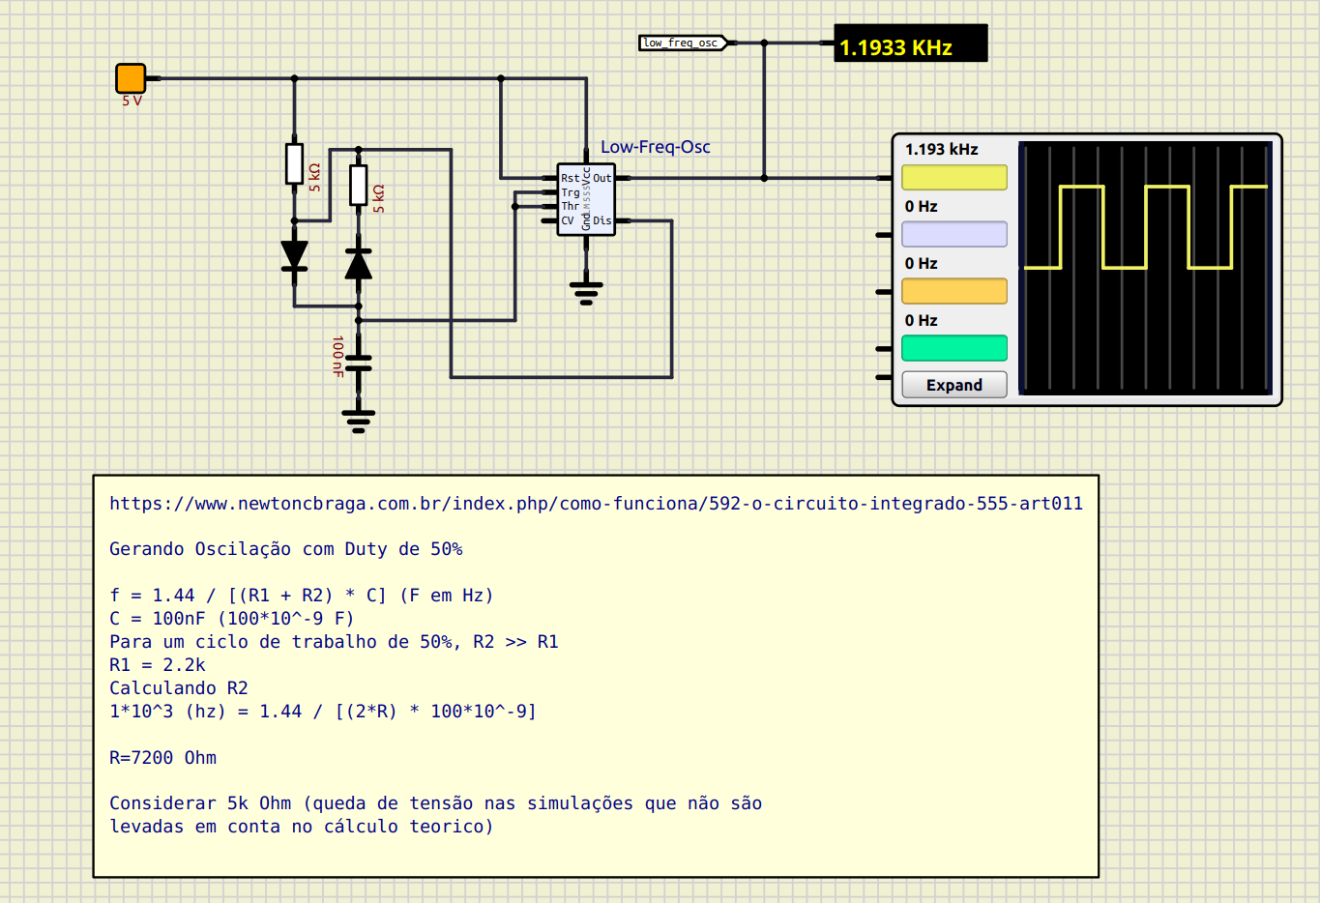
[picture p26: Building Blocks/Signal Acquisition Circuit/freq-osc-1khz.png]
  
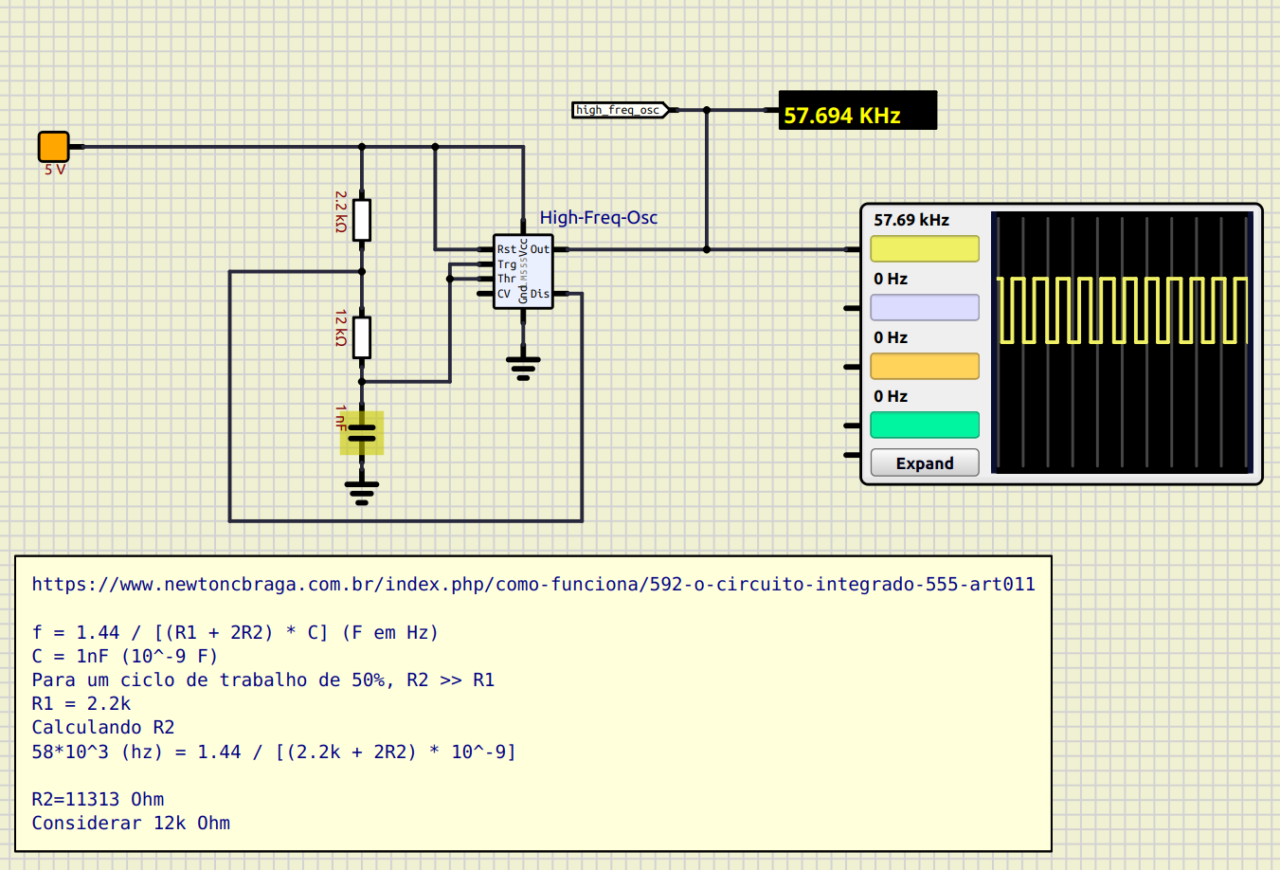
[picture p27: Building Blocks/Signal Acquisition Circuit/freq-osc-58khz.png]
  
</div>

* **High-Freq-Osc (58 kHz):** Gera a frequência de modulação para os LEDs. Isso garante que o sistema ignore a luz ambiente (contínua) ou lâmpadas fluorescentes (60 Hz).
* **Low-Freq-Osc(1KHz):** Provê a base de tempo para a lógica de multiplexação.

<div style="display: flex; gap: 10px;">
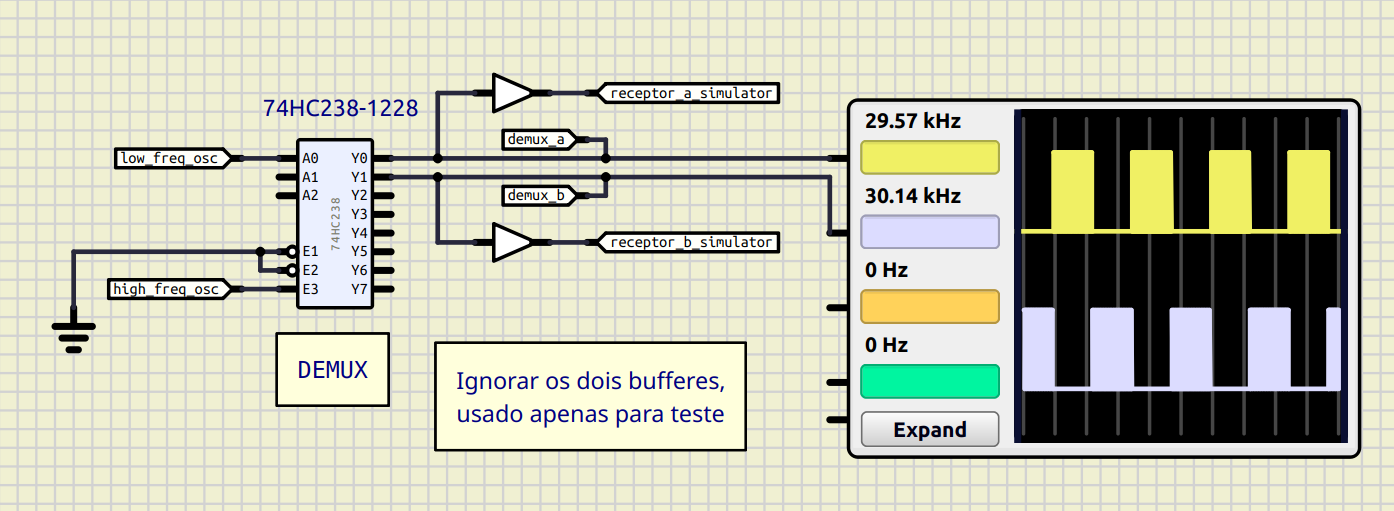
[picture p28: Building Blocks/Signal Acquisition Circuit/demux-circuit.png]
  
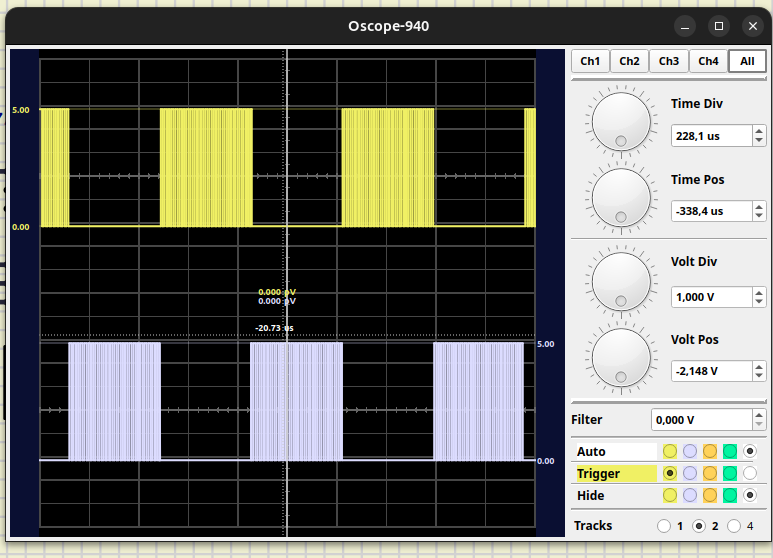
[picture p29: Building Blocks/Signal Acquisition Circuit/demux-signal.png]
  
</div>

* **Demultiplexação (74HC238):** Gerencia a ativação sequencial dos sensores para evitar interferência mútua (*cross-talk*).

#### 1.2. Condicionamento (Filtro RC)
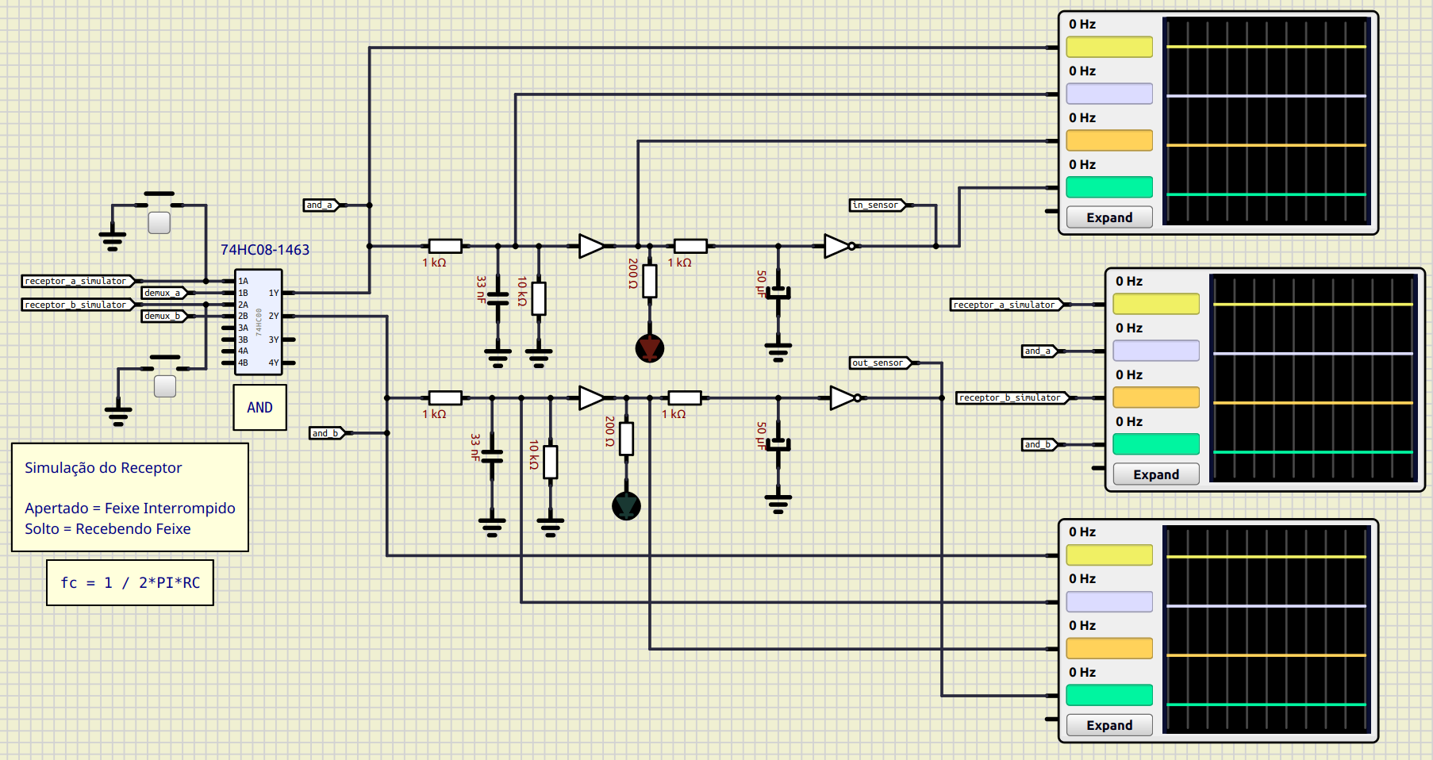
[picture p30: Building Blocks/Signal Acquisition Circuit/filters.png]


O sinal recebido passa por um filtro passivo para integração dos pulsos de 58 kHz:
$$fc = \frac{1}{2 \cdot \pi \cdot R \cdot C}$$
Entrega um nível lógico estável (**HIGH** para feixe livre, **LOW** para feixe interrompido).

### 2. Lógica de Identificação de Fluxo

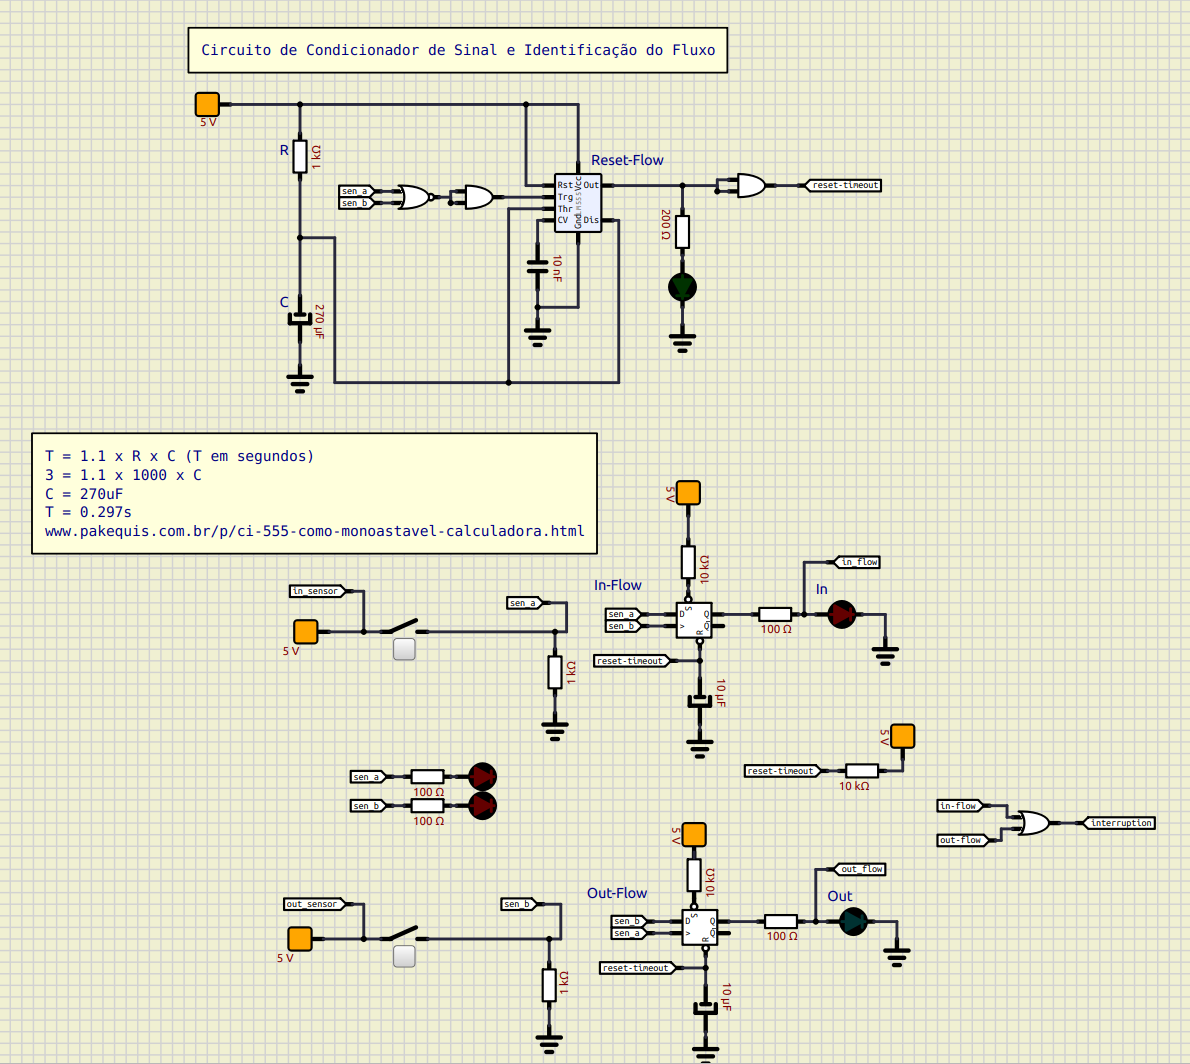
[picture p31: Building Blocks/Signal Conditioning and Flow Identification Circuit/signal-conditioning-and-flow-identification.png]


Processa a sequência de ativação dos sensores para determinar o sentido do movimento através da detecção de borda.

#### 2.1. Detecção de Sequência (Flip-Flops D)
* **Entrada (In-Flow):** Ativado quando o sinal do **Sensor A** precede o **Sensor B**.
* **Saída (Out-Flow):** Ativado quando o sinal do **Sensor B** precede o **Sensor A**.
Utiliza os *clocks* dos Flip-Flops para travar o estado no momento da interrupção sequencial.

#### 2.2. Temporização de Reset (Monoestável)
Utiliza um Timer 555 para evitar múltiplas contagens (repique) e garantir o processamento correto:
* **Fórmula:** $$T = 1.1 \cdot R \cdot C$$
* **Tempo de Travamento:** Aproximadamente **0.297 segundos** (utilizando $R=1k\Omega$ e $C=270\mu F$).
O sistema ignora novas entradas durante este intervalo e reseta a lógica para o próximo evento de fluxo.

### 3. Definição das Saídas (Interface com ESP32)



| Saída | Tipo | Descrição Operacional |
| :--- | :--- | :--- |
| **In-Flow** | Digital | Pulso HIGH indicando entrada de pessoa. |
| **Out-Flow** | Digital | Pulso HIGH indicando saída de pessoa. |
| **Interruption** | Digital | Saída da porta OR. Ativa em qualquer evento de fluxo. |

---

## 🔗 Referências Consultadas

* [O Circuito Integrado 555 - Newton C. Braga](https://www.newtoncbraga.com.br/index.php/como-funciona/592-o-circuito-integrado-555-art011)
* [Condicionamento de Sinais - Newton C. Braga](https://www.newtoncbraga.com.br/como-funciona/2416-art370.html)
* [74HC139/74LS139 Logic Guide](https://www.build-electronic-circuits.com/7400-series-integrated-circuits/74hc139-74ls139/)
* [ESP32 Intro and Pinout](https://esp32.implrust.com/esp32-intro/pinout.html)

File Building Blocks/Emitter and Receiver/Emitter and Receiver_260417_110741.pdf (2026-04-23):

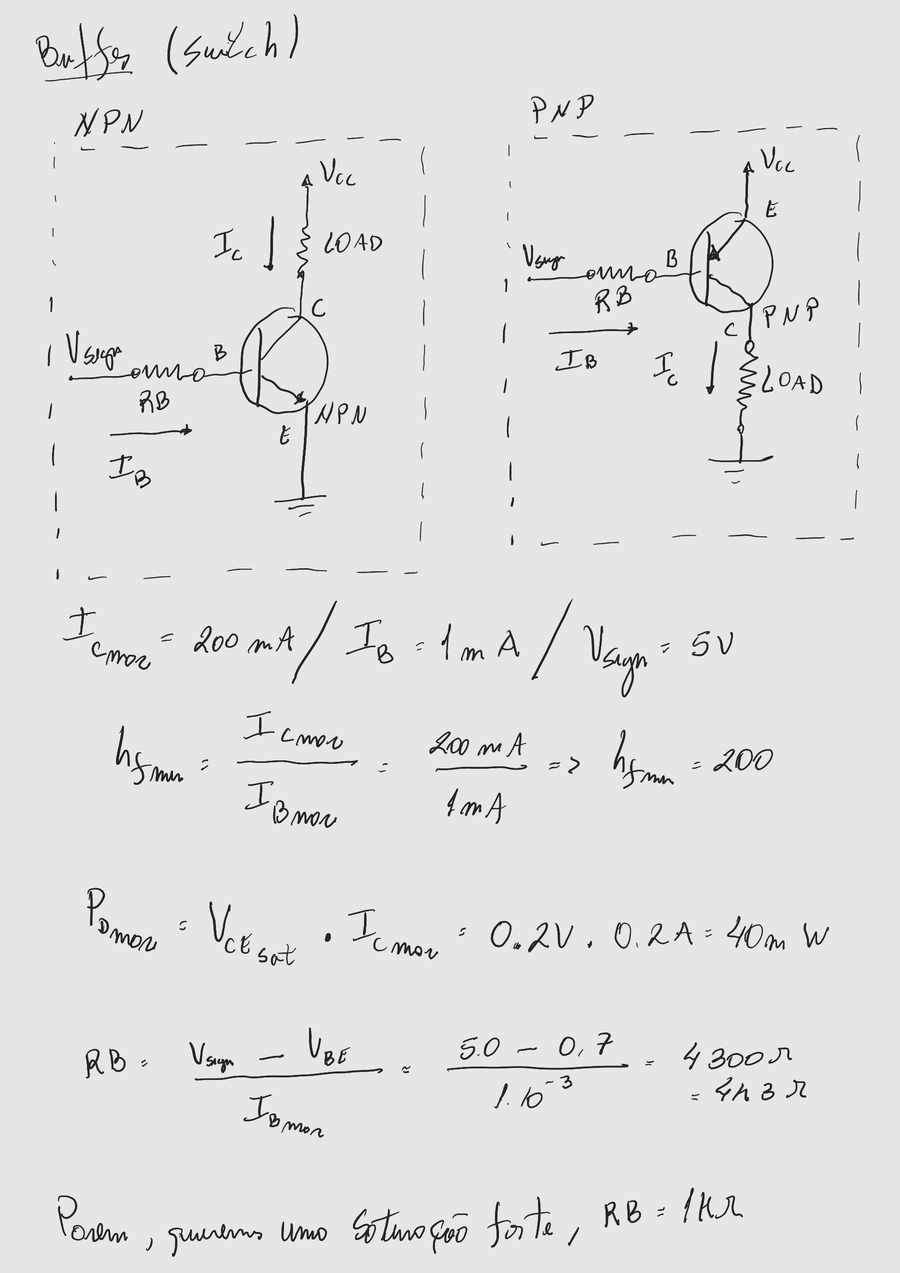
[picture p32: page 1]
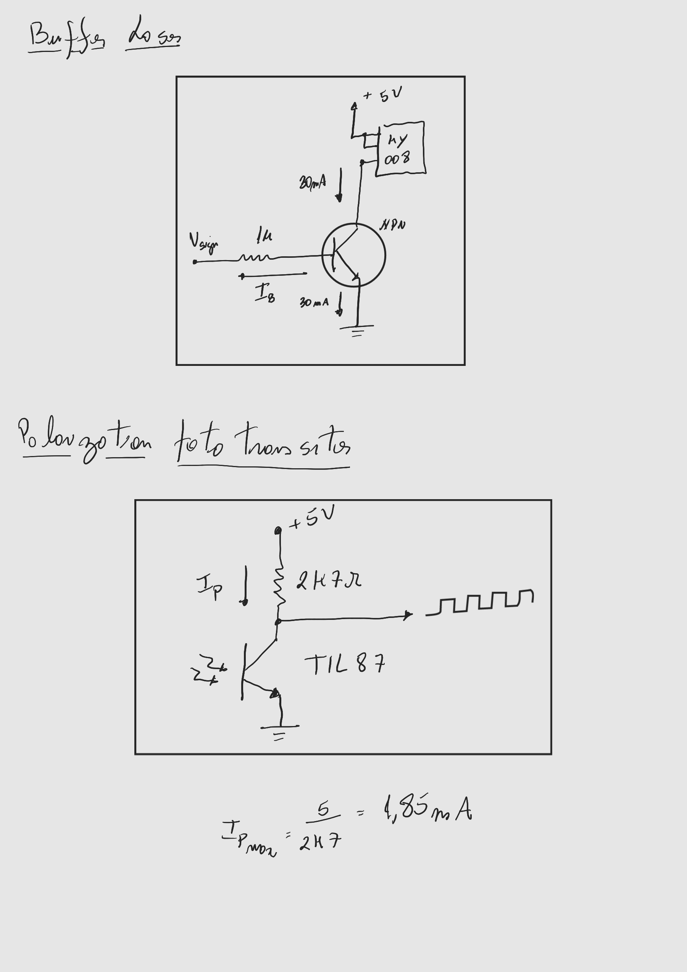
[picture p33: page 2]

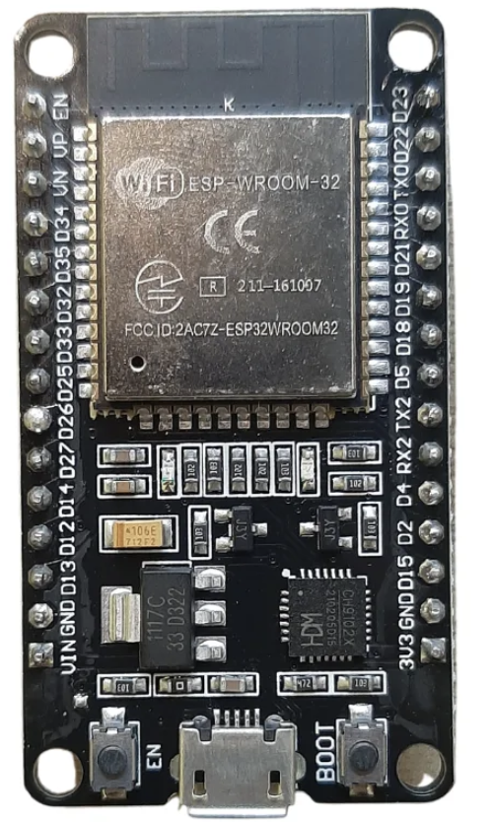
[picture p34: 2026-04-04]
Building Blocks/Processing e Server/ESP32-DevKit-V1.png

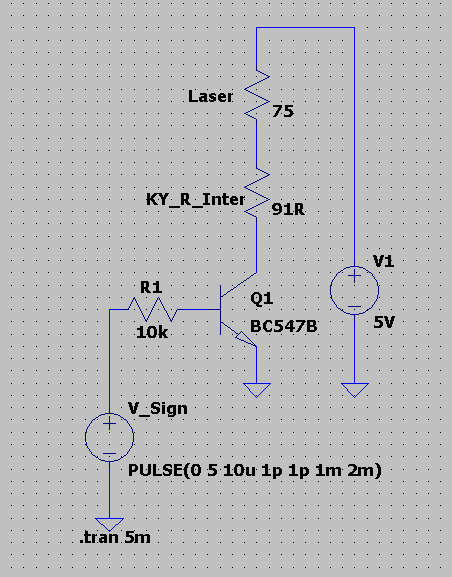
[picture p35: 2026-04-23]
Building Blocks/Emitter and Receiver/Buffer-KY-008/buffer-ky-008.png

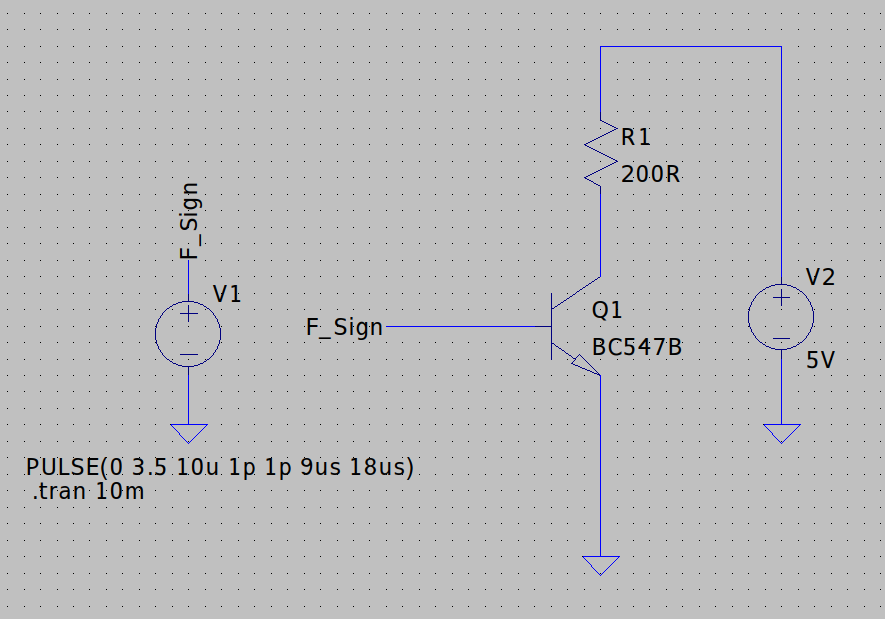
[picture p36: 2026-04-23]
Building Blocks/Emitter and Receiver/Polarization-TIL78/polarization-TIL78.png

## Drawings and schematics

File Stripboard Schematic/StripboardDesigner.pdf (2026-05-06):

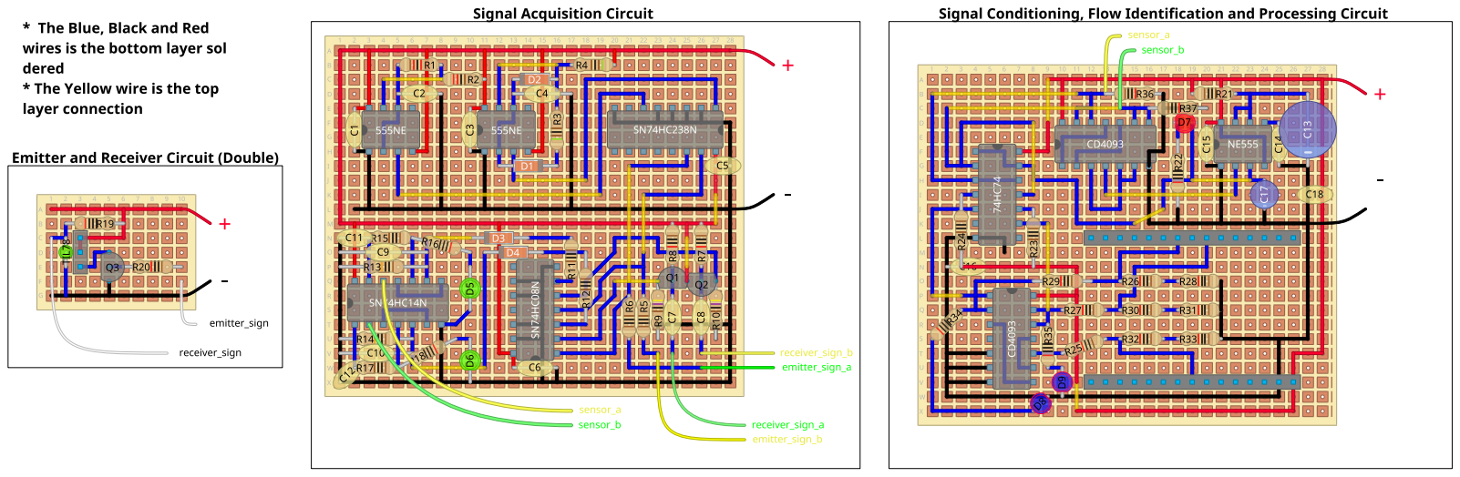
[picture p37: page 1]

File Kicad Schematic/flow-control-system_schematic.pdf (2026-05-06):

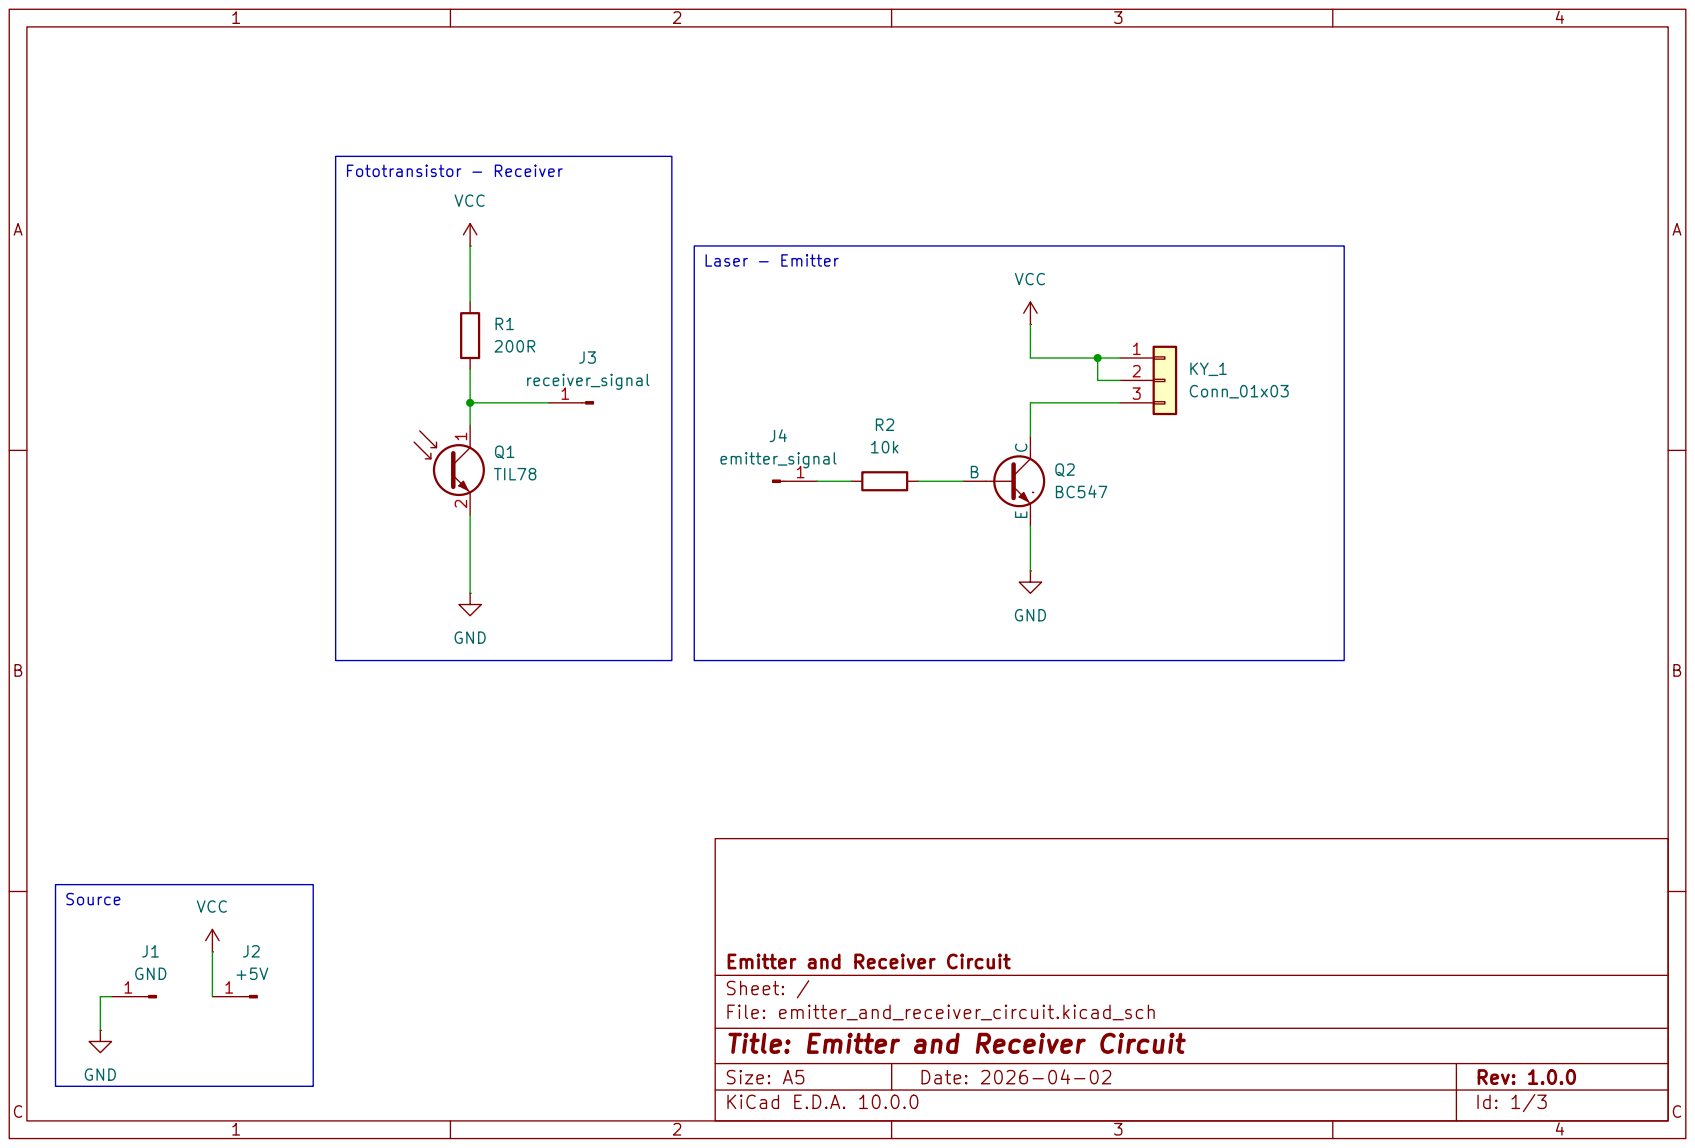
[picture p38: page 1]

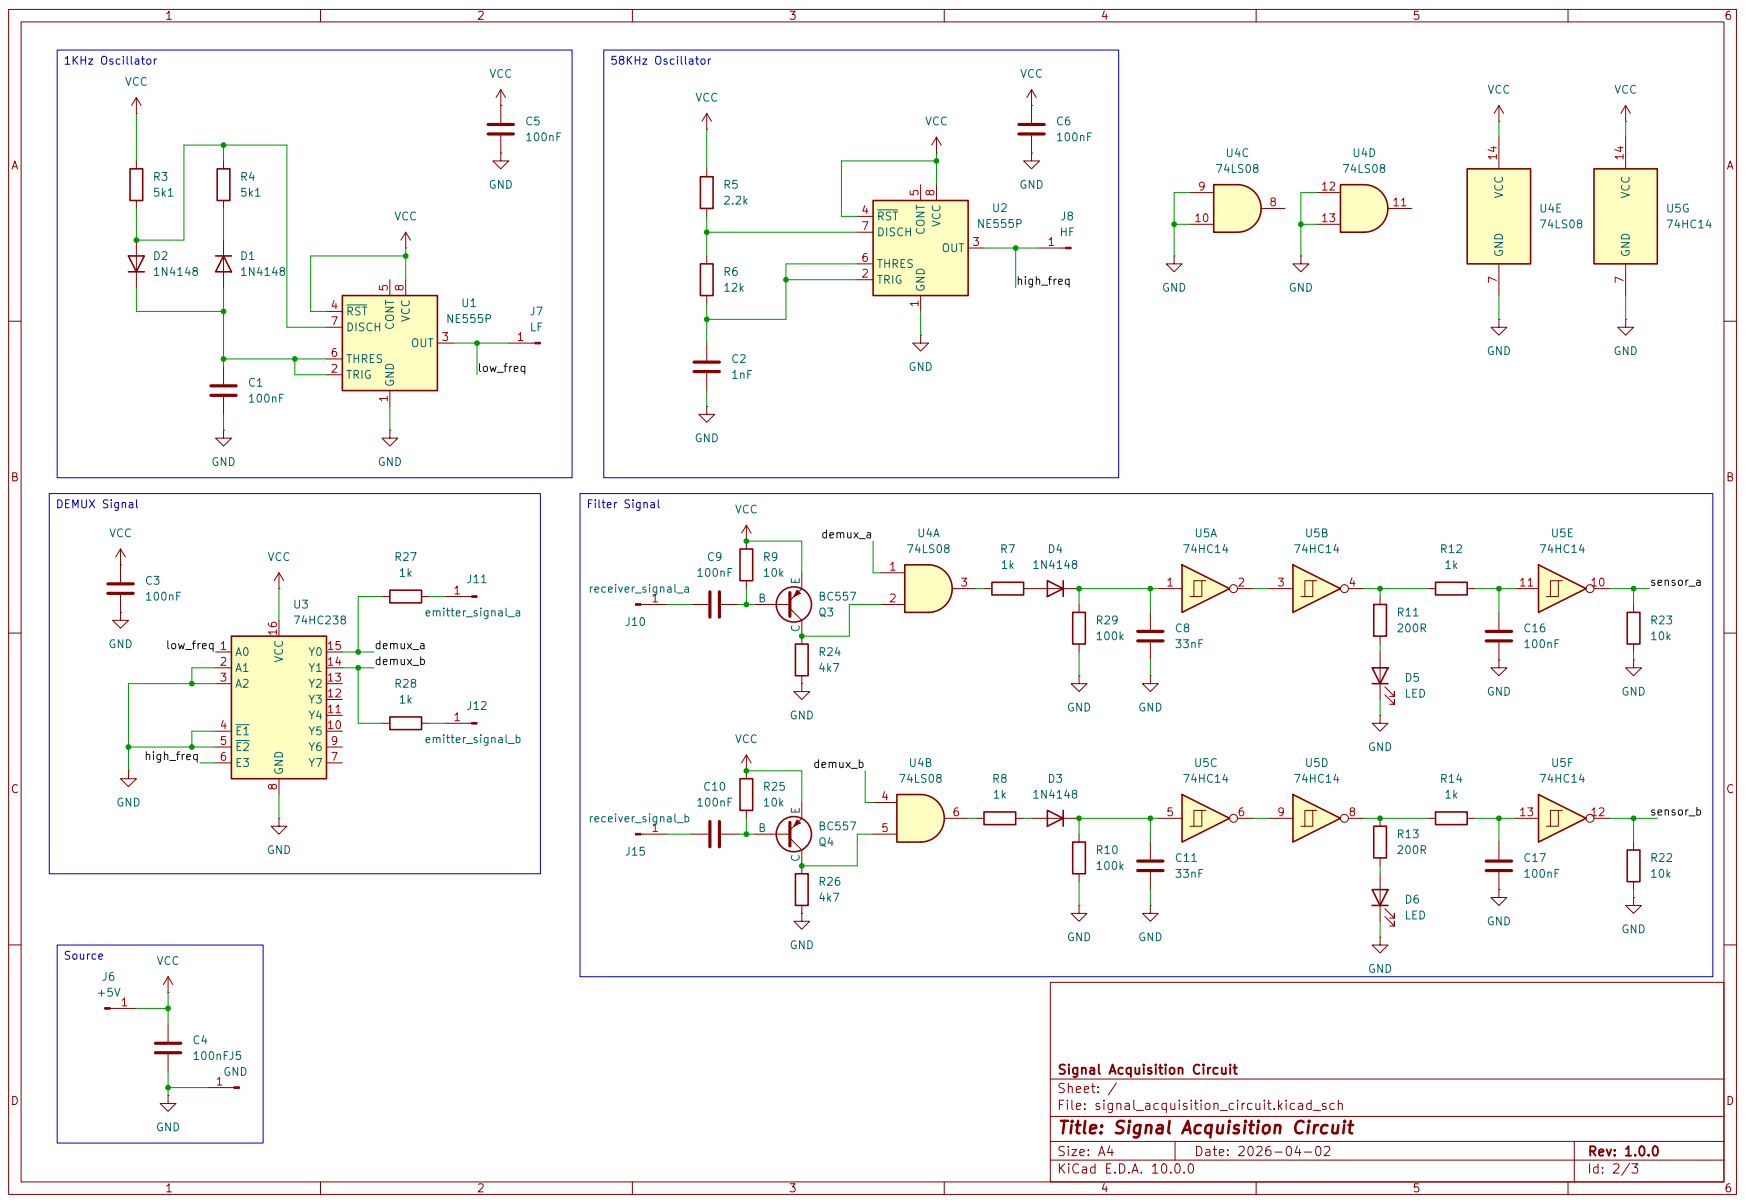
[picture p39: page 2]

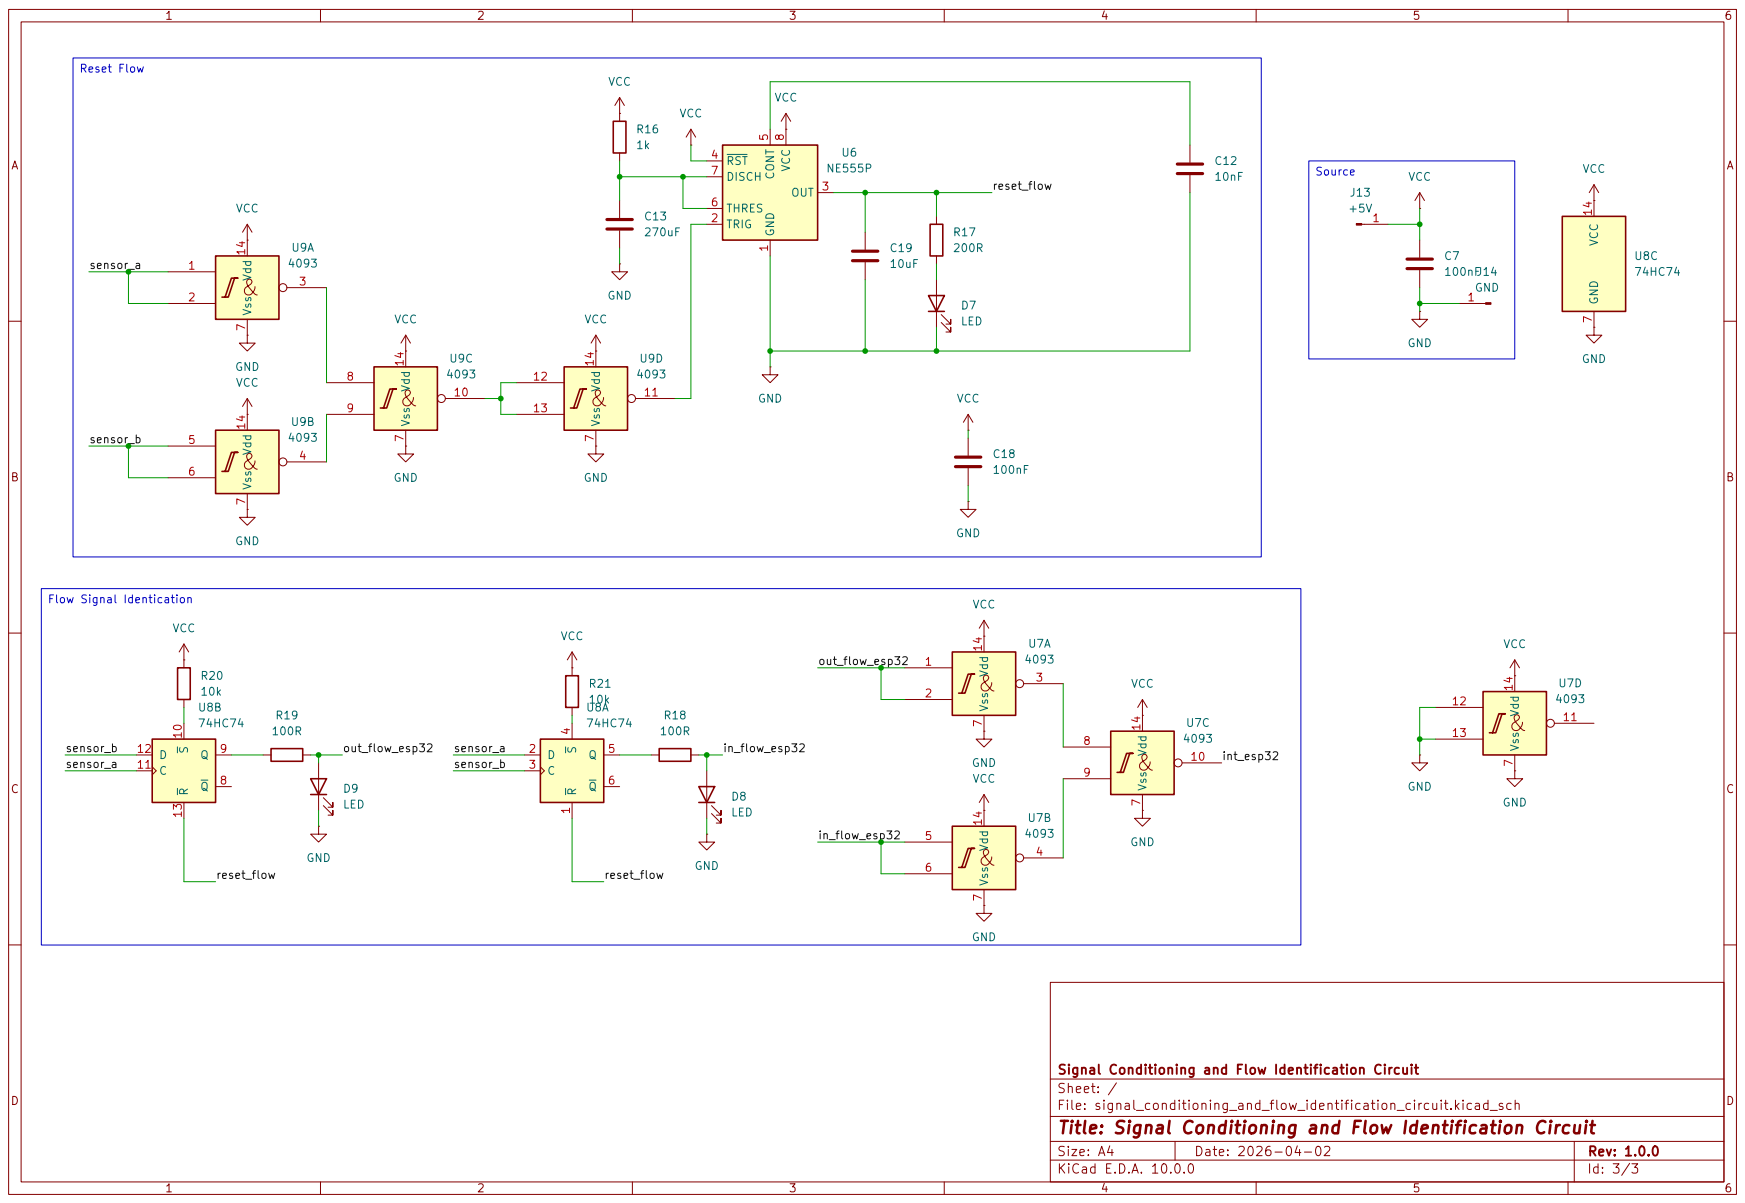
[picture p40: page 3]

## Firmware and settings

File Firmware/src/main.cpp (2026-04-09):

#include <Arduino.h>
#include <ArduinoJson.h>
#include <WiFi.h>
#include <ESPAsyncWebServer.h>
#include <LittleFS.h>
#include <esp_task_wdt.h>

#include <config.h>

#include <data_monitor.h>
#include <routine_monitor.h>

#include <webserver.h>

#include <index_request.h>
#include <analysis_request.h>
#include <raw_request.h>
#include <stats_request.h>

#include <simulate_request.h>
#include <cleanup_request.h>
#include <reset_request.h>
#include <download_request.h>
#include <delete_request.h>

#include <sample_api.h>
#include <stats_api.h>

AsyncWebServer *webServer;

DataMonitor *dataMonitor;
RoutineMonitor *routineMonitor;

// WebServer PAGE
WebServer *indexRequest;
WebServer *analysisRequest;
WebServer *rawRequest;
WebServer *statsRequest;

// WebServer GET
WebServer *simulateRequest;
WebServer *cleanupRequest;
WebServer *resetRequest;
WebServer *downloadRequest;
WebServer *deleteRequest;

// WebServer API
WebServer *sampleAPI;
WebServer *statsAPI;

void settingHardware() {
    Serial.begin(115200);

    // Configuração das portas In|Out do ESP32
    pinMode(LED_PIN, OUTPUT);

    pinMode(IN_FLOW, INPUT);
    pinMode(OUT_FLOW, INPUT);
    pinMode(INTERRUPTION, INPUT);

    esp_task_wdt_init(60, true);
}

void initLittleFS() {
    Serial.println("Attempting to mounting LittleFS, please wait...");

    // Iniciar LittleFS
    if (!LittleFS.begin(true)) {
        Serial.println("\nAn error occurred while trying to mount LittleFS.");
        abort();
    }

    Serial.println("LittleFS successfully mounted.\n");
}

void initWifi() {
    Serial.printf("SSID: %s\n", WIFI_SSID);
    Serial.print("Attempting to connect to WiFi, please wait...");

    // Conectar Wi-Fi
    WiFi.begin(WIFI_SSID, WIFI_PASSWORD);

    while (WiFi.status() != WL_CONNECTED) { 
        Serial.print(".");
        delay(500);
    }

    Serial.println("\nWiFi successfully connected");
    Serial.printf("IP: %s\n\n", WiFi.localIP().toString().c_str());
}

void initNTP() {
    Serial.print("Waiting for NTP synchronization...");

    // Sincroniza com os servidores NTP
    configTime(gmtOffset_sec, daylightOffset_sec, "pool.ntp.org", "time.google.com", "a.ntp.br");

    struct tm timeinfo;
    while (!getLocalTime(&timeinfo)) {
        Serial.print(".");
        delay(500);
    }

    Serial.println("\nNTP successfully synchronized.");
    Serial.println(&timeinfo, "Current Time: %A, %B %d %Y %H:%M:%S\n");
}

void initServer() {
    Serial.println("Server configuration and initialization");

    webServer = new AsyncWebServer(SERVER_PORT);

    dataMonitor = new DataMonitor(DATABASE, CLEANUP);

    // WebServer PAGE
    indexRequest = new IndexRequest(webServer, dataMonitor);
    indexRequest->onServer();

    analysisRequest = new AnalysisRequest(webServer, dataMonitor);
    analysisRequest->onServer();

    rawRequest = new RawRequest(webServer, dataMonitor);
    rawRequest->onServer();

    statsRequest = new StatsRequest(webServer, dataMonitor);
    statsRequest->onServer();

    // WebServer GET
    simulateRequest = new SimulateRequest(webServer, dataMonitor);
    simulateRequest->onServer();

    cleanupRequest = new CleanupRequest(webServer, dataMonitor);
    cleanupRequest->onServer();

    resetRequest = new ResetRequest(webServer, dataMonitor);
    resetRequest->onServer();

    downloadRequest = new DownloadRequest(webServer, dataMonitor);
    downloadRequest->onServer();

    deleteRequest = new DeleteRequest(webServer, dataMonitor);
    deleteRequest->onServer();

    // WebServer API
    sampleAPI = new SampleAPI(webServer, dataMonitor);
    sampleAPI->onServer();

    statsAPI = new StatsAPI(webServer, dataMonitor);
    statsAPI->onServer();

    webServer->begin();

    Serial.println("Server successfully initialized.\n");
}

void initRoutine() {
    Serial.println("Routine configuration and initialization");
    routineMonitor = new RoutineMonitor(dataMonitor, IN_FLOW, OUT_FLOW, INTERRUPTION, SAMPLE_STEP);
    Serial.println("Routine successfully initialized.\n");
}

void setup() {
    settingHardware();

    // Exibe Modo Debug
    Serial.printf("DEBUG: %s\n\n", DEBUG == 1 ? "True" : "False");

    VISUAL_INDICATOR_ON();

    // Aviso visual para indicar que o sistema esta sendo iniciado
    for(uint8_t i = 0; i < 8; ++i) {
        VISUAL_INDICATOR_ON();
        VISUAL_INDICATOR_OFF();
    }

    VISUAL_INDICATOR_ON();

    initLittleFS();
    initWifi();
    initNTP();
    initServer();
    initRoutine();

    VISUAL_INDICATOR_OFF();
}

void loop() {
    routineMonitor->running();
    delay(250);
}

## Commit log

2026-04-04 - initial commit
    [partitions.csv]
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2026-04-04 - otimizações no código, melhoria no sistema de banco de dados, ajustes de textos readme.md
2026-04-04 - alterações no sistema de reset e de cleanup
    [main.cpp]
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2026-04-04 - sistema de page para limpar a forma como as paginas são construidas no ESP32 - refactor do código main.cpp
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2026-04-04 - index page para receber raw data e analysis em uma única pagina - modificação da busca por datetime do data_monitor
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2026-04-06 - ajustes dos métodos das paginas e refatoração do código HTML via código para facilitar futuras manutenções
2026-04-06 - ajustes do html e style para funcionar tanto no celular como no computador
2026-04-06 - ajuste do CSS e do tamanho do painel com correções para funcionar a página na web PC e web celular
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2026-04-06 - modificação do Chart para adaptar o gráfico aos dados de amostragem
2026-04-06 database.db como sample para teste e generate.sql modificado para criar mais dados de teste
2026-04-06 - aumentado para 1 minuto o estouro do time do watchdog - adicionando sistema de progress handler no SQLite - removido wdt add e delete do dao
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2026-04-07 - correção de return do reset
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2026-04-07 - sistema de waiting - implementação do waiting no simulate e no cleanup
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2026-04-07 - generate fake data com 14 dias - database.db de exemplo com 14 dias de dados
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2026-04-07 - sistema de interrupção da porta Interruption e a leitura dos sensores InFlow e OutFlow - sistema de routine que roda a cada X minutos
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2026-04-07 - STEP dinâmico - sistema de semaforo para a interrupção - movendo o printf da interrupção para o controle principal para evitar crash da aplicação
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2026-04-08 - renomeando sensor monitor para routine monitor - ajustes no sistema de cleanup, considerando apenas as horas
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2026-04-08 - Adicionando reset de watchdog no Mutex para impedir o reinicio do sistema
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2026-04-08 - adicionado uma label de print para exibir a quantidade de memória ram do ESP32
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2026-04-08 - SampleJSON agora passa a referência do Sample ao invês da lista completa
2026-04-08 - removido Serial.print do método SQLiteStep e aumentado o LIMIT OPS do SQLite para 250
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2026-04-08 - criado o requirements.txt para a utilização do pio e dos comandos de build, upload, monitor etc do ESP32
2026-04-09 - adicionado PRINT do HEAP SIZE para avaliar o consumo de memória ao longo do tempo via log
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2026-04-09 - algumas alterações no sistema de routine, criado a routine e task para exibir dados do sistema
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2026-04-09 - utilização do FileSystem para verificar a existência do banco de dados
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2026-04-09 - implementação da busca de pastas do littlefs e exibição do mesmo - correção no sistema de routine do cleanup
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2026-04-09 - adicionado PRAGMA e criação do index no banco de dados do timestamp
2026-04-09 - modificação do nome deleteFile para deleteFileWith - deletando arquivos com iniciais 'tmp_' do LittleFS
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2026-04-09 - otimização do código raw page, resolvendo problema com leak de memória
2026-04-09 - resolução de alguns leaks de memória - não é indicado fazer new/delete dentro do AsyncWebServerRequest por algum motivo
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2026-04-15 - adicionando coredump no partition.csv para depuração de PANIC na firmware
    [partitions.csv]
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2026-04-15 - adicionando coredump ao final da tabela de partição
    [partitions.csv]
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2026-04-23 - versão 1.1 do Enclosure do Fotosensor
    [FotosensorEnclosure-Body-Back.obj, FotosensorEnclosure-Body-Top.obj, FotosensorEnclosure.3mf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]
2026-04-23 - Projeto Fotosensor enclosure - V1.2
    [FotosensorEnclosure-Body-Back.obj, FotosensorEnclosure-Body-Top.obj, FotosensorEnclosure.3mf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]
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2026-04-24 Kicad Schematic Circuit - Flow Control System
    [Flow-Control-System.kicad_pcb, Flow-Control-System.kicad_sch, emitter_and_receiver_circuit.kicad_sch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]
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2026-05-02 - ajuste no esquemático do Kicad, adicionado um buffer na entrada da AND do Schmitter para obter um buffer do receptor (TIL78), correção dos componentes do README.md e adicionado os componentes novos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
    [signal_acquisition_circuit.kicad_sch, signal_conditioning_and_flow_identification_circuit.kicad_sch]
2026-05-04 - ajuste do filtro passa-baixas da entrada das portas NOT Schmitt para não ocorrer a volta do sinal, além disso, adicionado um resistor de 100k como pull-down para descarregar o capacitor de filtro. 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
    [signal_acquisition_circuit.kicad_sch]
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2026-05-04 - correção do esquemático do oscilador 58KHz
    [signal_acquisition_circuit.kicad_sch]
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2026-05-04 - modificação no circuito de reset do 'signal conditioning and flow identification', removido o resistor de pull-up e colocado duas NAND, uma na entrada do trigger e uma na saída, assim, o OUT do 555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
    [signal_conditioning_and_flow_identification_circuit.kicad_sch]
2026-05-04 - removido a inversora NOT da saída do 555, revertendo o equivoco do projeto - foi substituido os resistores de pull-down R23 e R22 de 1k para 10k
    [signal_acquisition_circuit.kicad_sch, signal_conditioning_and_flow_identification_circuit.kicad_sch]
2026-05-06 - ajuste no circuito, removido dois capacitores de 10uF e adicionado apenas um no circuito de condicionamento de sinal - ajuste na lista de componentes do readme.md
    [signal_conditioning_and_flow_identification_circuit.kicad_sch]
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2026-05-07 - Enclosure do fotosensor versão 2.0
    [FotosensorEnclosure-Body-Back.obj, FotosensorEnclosure-Body-Bottom.obj, FotosensorEnclosure-Body-Top.obj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]
2026-05-07 - ajustes no da versão 2.0 enclosure do fotosensor
    [FotosensorEnclosure-Body-Bottom.obj, FotosensorEnclosure-Body-Top.obj, FotosensorEnclosure-Body.3mf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]
2026-05-07 - ajuste do projeto 3mf
    [FotosensorEnclosure-Body.3mf]
2026-05-08 - removido o arquivo .3mf do projeto
    [FotosensorEnclosure-Body.3mf]
2026-05-08 - modelagem da enclosure da mainboard do projeto
    [MainboardEnclosure.FCStd, MainboardEnclosure.obj, Spacer.obj]
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2026-05-08 - melhorias no modelo da caixa da mainboard, adicionado furos de saída do fio e do conector jack de alimentação
    [MainboardEnclosure.FCStd, MainboardEnclosure.obj]
2026-05-08 - adicionado a imagem wireframe do enclosure do fotosensor, atualização do readme
    [FotosensorEnclosure.FCStd]
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

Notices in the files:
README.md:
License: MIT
